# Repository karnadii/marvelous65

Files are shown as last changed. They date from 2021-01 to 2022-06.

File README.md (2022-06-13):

# Marvelous65 Keyboard Series
A 65% wireless hotswap keyboard with Rotary encoder, OLED display and RGB underglow.

## Marvelous65

## Marvelous65 Ergo


## Marvelous65 Split


# WARNING!!!
**FOR ADVANCED USER ONLY!!, THIS IS A DIY KEYBOARD AND NO ONE SELL IT, BUILDING THIS KEYBOARD REQUIRE YOU TO ORDER THE PCB FROM PCB MANU, SOLDER ALL THE COMPONENT YOURSELF, MAKING YOUR OWN PLATE AND CASE YOURSELF. IF YOU ONLY KNOW HOW TO ASSEMBLY A KEYBOARD, THIS IS NOT FOR YOU.**

This keyboard is inspired by luantty2's Candy BLE (https://github.com/luantty2/nRF52840-instruction). When I first saw that I was like "Beautiful! Marvelous!" but that would be nice to make that in 65%. So With no basic knowledge of electronic I brave myself to learn Kicad with the guide of https://wiki.ai03.com/. Basically this is just an nrfmicro 1.4 by Joric embedded in PCB. I also learn some basic Fusion 360 to make a keyboard case and plate.

When I finish designing this, I realize I am not he first one to design this, there is someone in zfrontier forum already done it, it is called Rainbow65, check it out https://www.zfrontier.com/app/flow/e1rpMAd9Nz75.
and there is someone planning an IC for similar layout and feature. 

## Bootloader
Before flashing the firmware, you have to flash the bootloader first. Follow the nrfmicro guide to flash the bootloader https://github.com/joric/nrfmicro/wiki/Bootloader
## Firmware
The firmware will use [ZMK](https://zmkfirmware.dev/). Basic setup ZMK firmware https://zmkfirmware.dev/docs/development/setup.
copy the firmware file to `app/boards/shields`. Edit the keymap or any other feature as you want and build the firmware using the following command 
```bash
west build -p -b nrfmicro_13 -- -DSHIELD=marvelous65_rev2
west build -p -b nrfmicro_13 -- -DSHIELD=marvelous65_ergo
west build -p -b nrfmicro_13 -- -DSHIELD=marvelous65_split_right
west build -p -b nrfmicro_13 -- -DSHIELD=marvelous65_split_left
```

## Features
- Dual mode wireless and wired
- rotary encoder
- oled display 
- rgb underglow
- hotswap (except split version)
- multilayout (except ergo version)

## PCB 
the marvelous65 standard and split version I route it manually. the ergo version I semi auto route it with freerouting. I know a little about electronic, if you have some suggestion or want to coorect the PCB/schematic feel free to make a PR or open an issue.
### Marvelous65
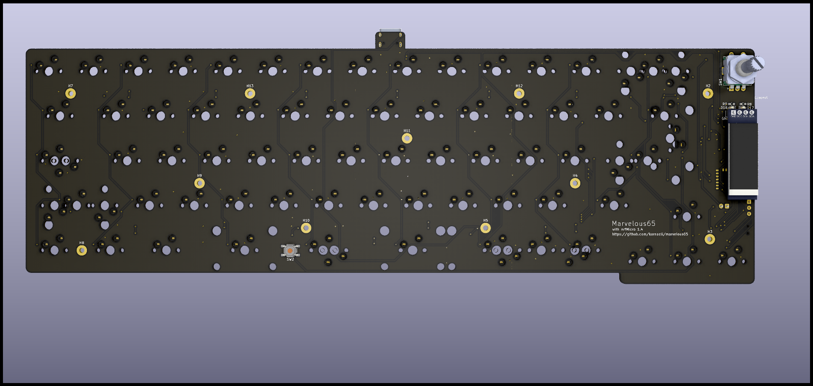
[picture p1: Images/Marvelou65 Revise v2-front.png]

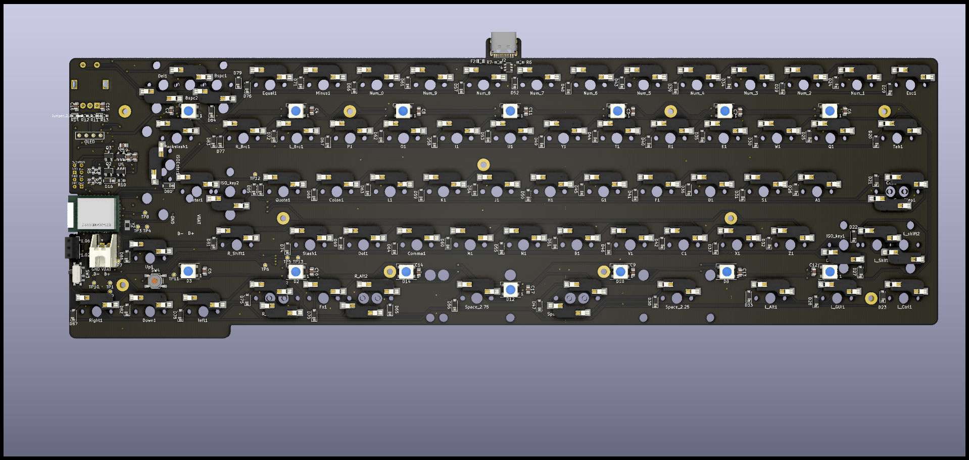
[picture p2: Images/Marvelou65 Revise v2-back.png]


### Marvelous65 Ergo
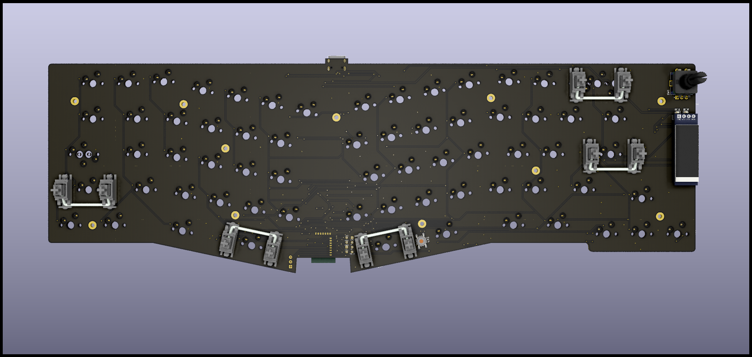
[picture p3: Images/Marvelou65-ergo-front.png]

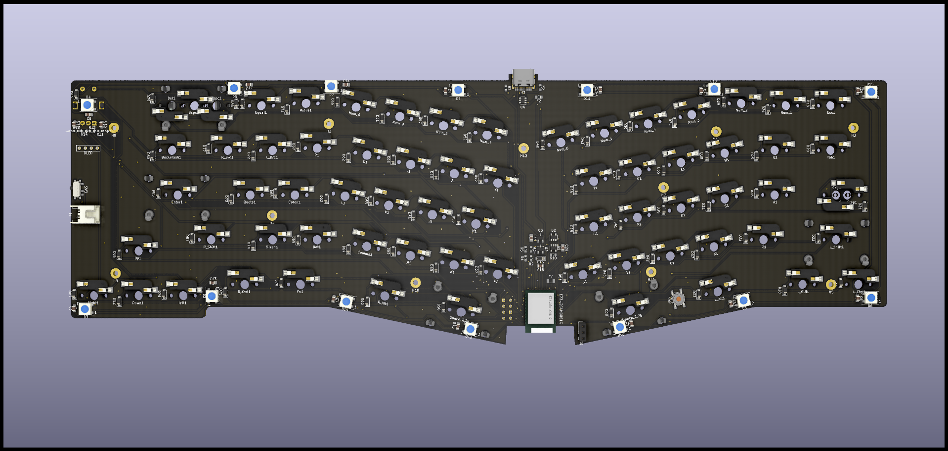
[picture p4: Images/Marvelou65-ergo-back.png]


### Marvelous65 Split
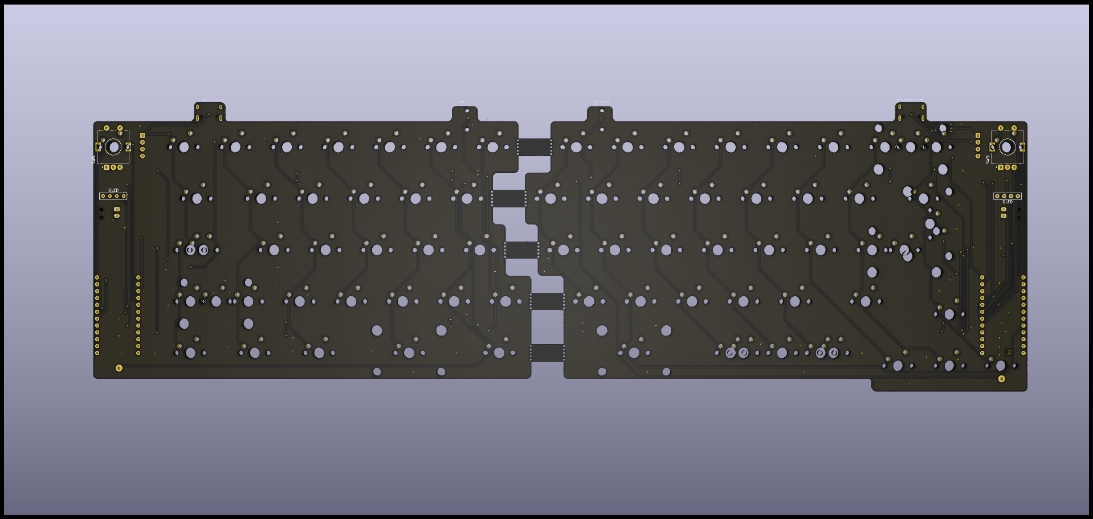
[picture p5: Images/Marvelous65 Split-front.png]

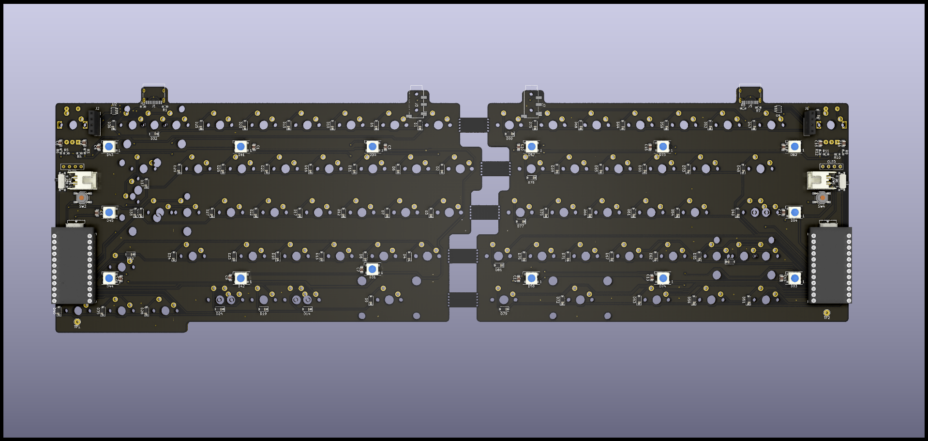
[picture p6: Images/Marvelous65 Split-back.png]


## Layout
### Marvelous65

try it in [KLE](http://www.keyboard-layout-editor.com/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'&_a:6&w:2.25%3B&=Enter&_x:2&a:7%3B&=%3B&@_w:1.25%3B&=&=&_x:0.75&a:6&w:2.25%3B&=Shift&_a:4%3B&=Z&=X&=C&=V&=B&=N&=M&=%3C%0A,&=%3E%0A.&=%3F%0A%2F%2F&_a:6&w:1.75%3B&=Shift%3B&@_y:-0.75&x:17.25&a:7%3B&=%E2%86%91%3B&@_y:-0.25&x:3&a:6&w:1.25%3B&=Ctrl&_w:1.25%3B&=Win&_w:1.25%3B&=Alt&_a:7&w:6.25%3B&=&_a:6%3B&=Alt&=Fn&=Ctrl%3B&@_y:-0.75&x:16.25&a:7%3B&=%E2%86%90&=%E2%86%93&=%E2%86%92%3B&@_x:6.75&w:2.25%3B&=&_w:1.25%3B&=&_w:2.75%3B&=&_w:1.5%3B&=&_w:1.5%3B&=) (Support ISO, stplit backspace, split spacebar, stepped caps)

### Marvelous65 Ergo
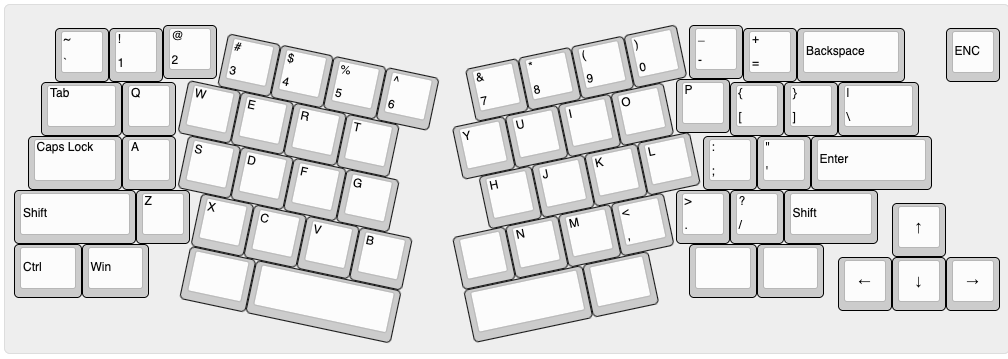
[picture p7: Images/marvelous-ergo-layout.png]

try it in [KLE](http://www.keyboard-layout-editor.com/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'&_a:6&w:2.25%3B&=Enter%3B&@_w:2.25%3B&=Shift&_a:4%3B&=Z&_x:9%3B&=%3E%0A.&=%3F%0A%2F%2F&_a:6&w:1.75%3B&=Shift%3B&@_y:-0.75&x:16.25&a:7%3B&=%E2%86%91%3B&@_y:-0.25&a:6&w:1.25%3B&=Ctrl&_w:1.25%3B&=Win&_x:10&a:7&w:1.25%3B&=&_w:1.25%3B&=%3B&@_y:-0.75&x:15.25%3B&=%E2%86%90&=%E2%86%93&=%E2%86%92%3B&@_r:12&rx:3.05&ry:4.35&y:-1.0999999999999996&x:0.20000000000000018&a:4%3B&=X&=C&=V&=B%3B&@_x:0.20000000000000018&a:7&w:1.25%3B&=&_w:2.75%3B&=%3B&@_rx:3.15&ry:3.35&y:-1.1&x:-0.1499999999999999&a:4%3B&=S&=D&=F&=G%3B&@_rx:3.25&ry:2.35&y:-1.1&x:-0.25%3B&=W&=E&=R&=T%3B&@_rx:3.35&ry:1.35&y:-1.1&x:0.3999999999999999%3B&=%23%0A3&=$%0A4&=%25%0A5&=%5E%0A6%3B&@_r:-12&rx:12.1&y:-1.1&x:-3.5999999999999996%3B&=%2F&%0A7&=*%0A8&=(%0A9&=)%0A0%3B&@_rx:12.2&ry:2.35&y:-1.1&x:-3.9499999999999993%3B&=Y&=U&=I&=O%3B&@_rx:12.3&ry:3.35&y:-1.1&x:-3.5500000000000007%3B&=H&=J&=K&=L%3B&@_rx:12.4&ry:4.35&y:-1.0999999999999996&x:-4.15&a:7%3B&=&_a:4%3B&=N&=M&=%3C%0A,%3B&@_rx:12.525&ry:5.5415&y:-1.2915&x:-4.025&a:7&w:2.25%3B&=&_w:1.25%3B&=) (Support split backspace and stepped caps) 

### Marvelous65 Split
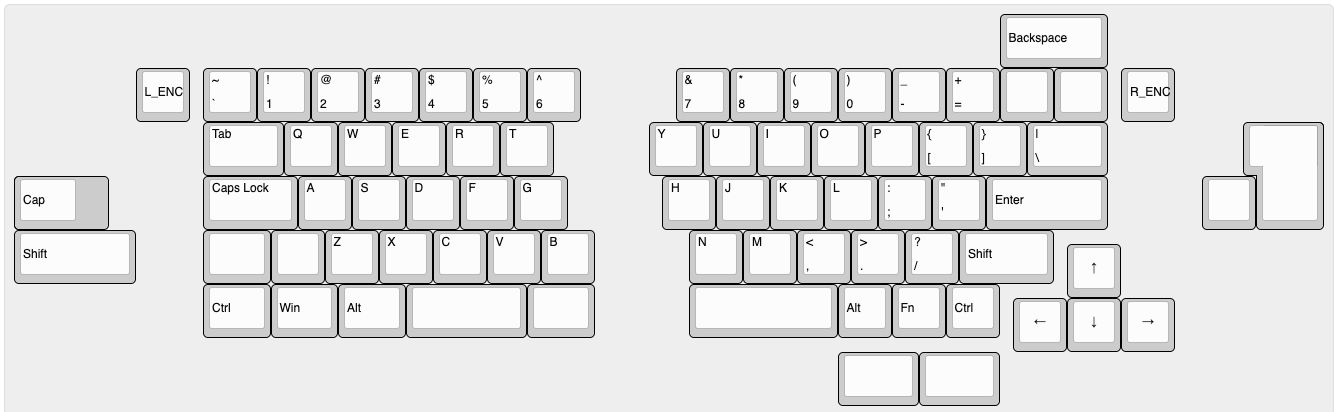
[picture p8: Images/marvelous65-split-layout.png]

try in in [KLE](http://www.keyboard-layout-editor.com/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'&_a:6&w:2.25%3B&=Enter&_x:1.75&a:7%3B&=%3B&@_a:6&w:2.25%3B&=Shift&_x:1.25&a:7&w:1.25%3B&=&=&_a:4%3B&=Z&=X&=C&=V&=B&_x:1.75%3B&=N&=M&=%3C%0A,&=%3E%0A.&=%3F%0A%2F%2F&_a:6&w:1.75%3B&=Shift%3B&@_y:-0.75&x:19.5&a:7%3B&=%E2%86%91%3B&@_y:-0.25&x:3.5&a:6&w:1.25%3B&=Ctrl&_w:1.25%3B&=Win&_w:1.25%3B&=Alt&_a:7&w:2.25%3B&=&_w:1.25%3B&=&_x:1.75&w:2.75%3B&=&_a:6%3B&=Alt&=Fn&=Ctrl%3B&@_y:-0.75&x:18.5&a:7%3B&=%E2%86%90&=%E2%86%93&=%E2%86%92%3B&@_x:15.25&w:1.5%3B&=&_w:1.5%3B&=) (Support ISO, stplit backspace, split spacebar, stepped caps)

## Case
All the case is all 3d printed, except the ergo version have acrylic version case. The case have 3 part, top, middle and bottom. the top and bottom using PLA with 20% infill, while the middle use transparent PLA with 100% infill(to diffuse the underglow RGB) I only know some basic 3d knowledge, so if my case is not to your liking you can design your own case and make a PR or keep it to yourself. Here some rendered Image from fusion 360. The case is top mount. Using M2x5/M2x6 threaded insert and M2 screw (I don't remember the exact size, just buy a set of m2 screw.) The plate for marvelous65 and marvelous65 ergo is sandwiched between top case and bottom case, 

### Marvelous65

### Marvelous65 Ergo
#### Acrylic case

#### 3d printed case


### Marvelous65 Split
I am too lazy while designing this one, so I only design ANSI layout case. The plate is integrated to the case, so if you want different layout you want to make another case.
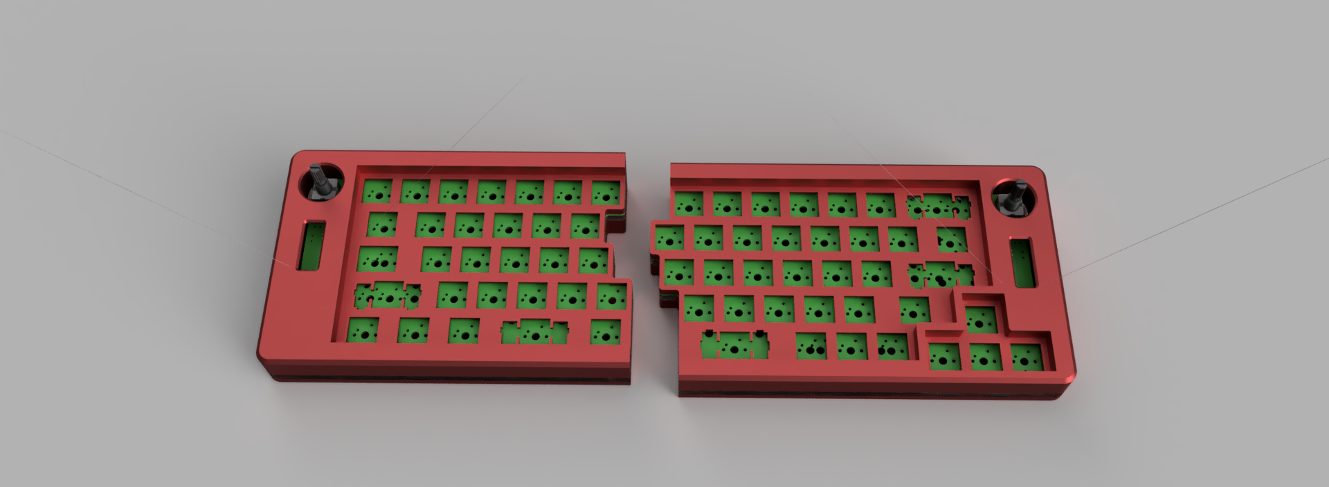
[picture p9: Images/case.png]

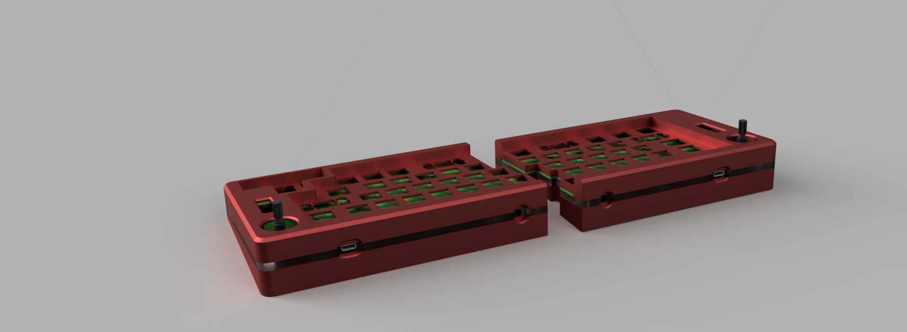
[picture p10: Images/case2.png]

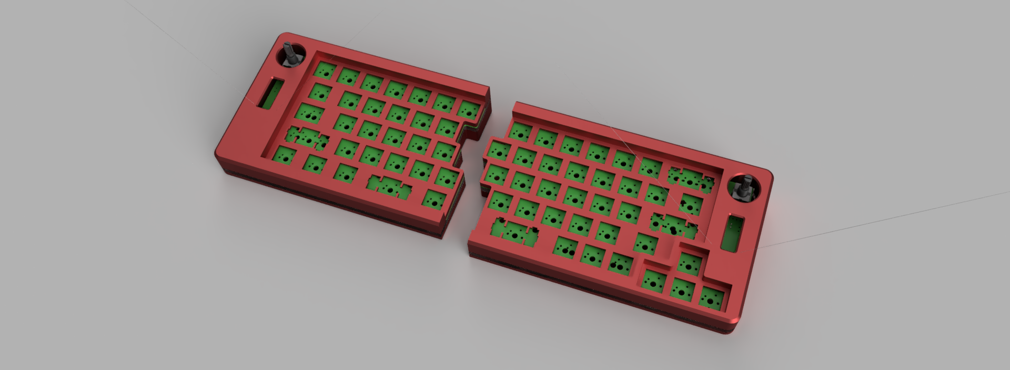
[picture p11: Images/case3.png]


## GIF

https://user-images.githubusercontent.com/18657277/117118259-c4ab1200-adba-11eb-80a2-d7a4a54a5487.mp4

https://user-images.githubusercontent.com/18657277/117118099-8dd4fc00-adba-11eb-8657-396213f3611c.mp4

## BOM
See BOM file for JLCPCB in release page.
also I added IBOM for reference when you will solder it yourself

Marvelous65 IBOM https://karnadii.github.io/marvelous65/Marvelous65/Hardware/bom/ibom.html

Marvelous65-ergo IBOM https://karnadii.github.io/marvelous65/Marvelous65-ergo/Hardware/bom/ibom.html

Marvelous65-split IBOM https://karnadii.github.io/marvelous65/Marvelous65-split/Hardware/bom/ibom.html

## Battery
any lipo battery will do, i use 2.4 JST XH connector. it is better to use 3mm thickness battery.

for the pcb [JST XH2.54 Right Angle Pin Header Connector 2P](https://www.aliexpress.com/item/33008489410.html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,searchweb201602_,searchweb201603_)
for battery [JST XH 2PIN male](https://www.aliexpress.com/item/32996835431.html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,searchweb201602_,searchweb201603_).
All the battery that I purchase have no connector/socket, so I have to solder it myself. Be carefull when soldering, pay attention to the negative and positive of the battery.

I am using this battery. Ignore the label the actual size is 3300mAh.



## TODO
- add acrylic case version
- add multi layout case for split version
- fix ergo version plate (misaligned one screw hole)
- marvelous65 ergo 3d printed case split version
- designing logo and silkscreen
- add assembly guide

## Support Me
Help me order prototype PCB for next revision



## Reference 
- nrfmicro 1.4 https://github.com/joric/nrfmicro/wiki
- nice60 pcb https://github.com/Nicell/nice60
- ZMK firmware https://github.com/zmkfirmware/zmk

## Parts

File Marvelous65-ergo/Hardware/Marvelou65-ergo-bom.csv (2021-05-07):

Comment | Designator | Footprint | LCSC
2 | Bspc2 | MX_Only:MXOnly-2U-Hotswap
10uF | C18,C19,C20 | Capacitor_SMD:C_0805_2012Metric_Pad1.15x1.40mm_HandSolder | C15850
0.1uF | C2,C3,C4,C5,C6,C7,C8,C9,C10,C11,C12,C13,C14,C15,C16,C17 | Capacitor_SMD:C_0805_2012Metric_Pad1.15x1.40mm_HandSolder | C49678
WS2812B | D2,D3,D4,D5,D6,D7,D8,D9,D10,D11,D12,D13,D14,D15 | LED_SMD:LED_WS2812B_PLCC4_5.0x5.0mm_P3.2mm | C114586
1N5819 | D16 | Diode_SMD:D_SOD-123 | C169540
BLUE | D17 | LED_SMD:LED_0603_1608Metric_Pad1.05x0.95mm_HandSolder | C375446
RED | D18 | LED_SMD:LED_0603_1608Metric_Pad1.05x0.95mm_HandSolder | C375450
D | D19,D20,D21,D22,D23,D24,D25,D26,D27,D28,D29,D30,D31,D32,D33,D34,D35,D36,D37,D38,D39,D40,D41,D42,D43,D44,D45,D46,D48,D49,D50,D51,D52,D53,D54,D55,D56,D57,D58,D59,D60,D61,D62,D63,D64,D65,D66,D67,D68,D69,D70,D71,D72,D73,D74,D75,D76,D77,D78,D79,D80,D81,D82,D83,D84,D85,D86,D87 | Diode_SMD:D_SOD-123 | C81598
2.25 | Enter1,L_Shift1 | MX_Only:MXOnly-2.25U-Hotswap
1 | Num_0,Esc1,Num_1,Minus1,Equal1,Bspc1,Del1,Q1,W1,E1,R1,T1,Y1,U1,I1,O1,P1,L_Brc1,R_Brc1,S1,D1,F1,G1,H1,J1,K1,L1,Colon1,Quote1,Z1,X1,C1,V1,B1,N1,M1,Comma1,Dot1,Slash1,Up1,Down1,Right1,left1,A1,Num_2,B2,Num_3,Num_4,Num_5,Num_6,Num_7,Num_8,Num_9 | MX_Only:MXOnly-1U-Hotswap
500mA | F2 | Fuse:Fuse_0805_2012Metric_Pad1.15x1.40mm_HandSolder | C261942
MountingHole | H2,H3,H4,H5,H7,H8,H9,H10,H11,H12,H13 | MountingHole:MountingHole_2.2mm_M2_Pad
USB_C_Receptacle_USB2.0 | J2 | Connector_USB:USB_C_Receptacle_HRO_TYPE-C-31-M-12 | C165948
Conn_01x04 | J3 | nrfmicro:connector_swd
Conn_01x02 | J4 | Connector_JST:JST_XH_S2B-XH-A-1_1x02_P2.50mm_Horizontal | C157931
Conn_01x04 | J5 | nrfmicro:connector_usb
Conn_01x03 | J6 | Connector_PinSocket_2.54mm:PinSocket_1x03_P2.54mm_Vertical
Jumper_2_Bridged | JP1,JP2 | SofleKeyboard-footprint:Jumper
1.25 | L_Ctrl1,L_GUI1,L_Alt1,Cap_Step1 | MX_Only:MXOnly-1.25U-Hotswap
OLED | OL1 | kbd:OLED
AO3407 | Q2,Q3 | Package_TO_SOT_SMD:TSOT-23 | C693136
RPROG_10K/2K | R10 | Resistor_SMD:R_0603_1608Metric_Pad1.05x0.95mm_HandSolder | C22975
10k | R11,R12,R13,R14 | Resistor_SMD:R_0603_1608Metric_Pad1.05x0.95mm_HandSolder | C25804
100K | R2 | Resistor_SMD:R_0603_1608Metric_Pad1.05x0.95mm_HandSolder | C25803
820K | R3 | Resistor_SMD:R_0603_1608Metric_Pad1.05x0.95mm_HandSolder | C23252
2M | R4,R5 | Resistor_SMD:R_0603_1608Metric_Pad1.05x0.95mm_HandSolder | C22976
5.1K | R6,R7 | Resistor_SMD:R_0603_1608Metric_Pad1.05x0.95mm_HandSolder | C23186
1K | R8,R9 | Resistor_SMD:R_0603_1608Metric_Pad1.05x0.95mm_HandSolder | C21190
1 | R_Ctrl1,Fn1,R_Alt1 | MX_Only:MXOnly-1.25U-Hotswap
1.75 | R_Shift1,Cap1 | MX_Only:MXOnly-1.75U-Hotswap
Rotary_Encoder_Switch | SW1 | Rotary_Encoder:RotaryEncoder_Alps_EC11E-Switch_Vertical_H20mm | C470748
SW_PUSH | SW2,SW4 | Button_Switch_SMD:SW_SPST_TL3342 | C318884
SW_SPDT | SW3 | Button_Switch_SMD:SW_SPDT_PCM12 | C221841
2.25 | Space_2.25 | MX_Only:MXOnly-2.25U-Hotswap-ReversedStabilizers
2.75 | Space_2.75 | MX_Only:MXOnly-2.75U-Hotswap-ReversedStabilizers
1.5 | Tab1,Backslash1 | MX_Only:MXOnly-1.5U-Hotswap
AP2112K-3.3 | U2 | Package_TO_SOT_SMD:SOT-23-5 | C51118
E73-2G4M08S1C-52840 | U3 | nrfmicro:E73-2G4M08S1C-52840 | C356849
USBLC6-2SC6 | U4 | Package_TO_SOT_SMD:SOT-23-6 | C558442
TP4054 | U5 | Package_TO_SOT_SMD:SOT-23-5 | C32574
32.768KHZ | Y2 | Crystal:Crystal_SMD_3215-2Pin_3.2x1.5mm | C479190

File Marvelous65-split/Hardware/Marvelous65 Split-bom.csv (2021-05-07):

Comment | Designator | Footprint | LCSC
0.1uF | C1,C2,C3,C4,C5,C6,C7,C8,C9,C10,C11,C12,C13,C14,C15,C16,C17,C18 | Capacitor_SMD:C_0805_2012Metric_Pad1.15x1.40mm_HandSolder | C49678
D | D1,D2,D3,D4,D5,D6,D7,D8,D9,D10,D11,D12,D13,D14,D15,D16,D17,D18,D19,D20,D21,D22,D23,D24,D25,D26,D27,D28,D29,D32,D33,D34,D35,D36,D37,D38,D39,D40,D46,D47,D48,D49,D50,D51,D52,D53,D54,D55,D56,D59,D60,D61,D62,D63,D64,D65,D66,D67,D68,D69,D70,D71,D72,D75,D76,D77,D78,D79,D80,D81 | Diode_SMD:D_SOD-123 | C81598
WS2812B | D30,D31,D41,D42,D43,D44,D45,D57,D58,D73,D74,D82,D83,D84 | LED_SMD:LED_WS2812B_PLCC4_5.0x5.0mm_P3.2mm
MX-NoLED | ISO_ENTER1 | MX_Only:MXOnly-ISO-ROTATED-ReversedStabilizers-NoLED
USB_C_Receptacle_USB2.0 | J1,J5 | Connector_USB:USB_C_Receptacle_HRO_TYPE-C-31-M-12 | C165948
Conn_01x04 | J2,J6 | Connector_PinSocket_2.54mm:PinSocket_1x04_P2.54mm_Vertical
AudioJack4 | J3,J7 | Connector_Audio:Jack_3.5mm_PJ320D_Horizontal | C15139
Conn_01x02 | J4,J8 | Connector_JST:JST_XH_S2B-XH-A_1x02_P2.50mm_Horizontal | C157931
Jumper_2_Bridged | JP1,JP2,JP3,JP4 | SofleKeyboard-footprint:Jumper
1.5 | K_BACKSLASH1,K_CTRL1,K_ALT1,K_TAB1 | MX_Only:MXOnly-1.5U-NoLED
2 | K_BSPC1 | MX_Only:MXOnly-2U-NoLED
2.25 | K_ENTER1,K_LSHIFT1 | MX_Only:MXOnly-2.25U-NoLED
MX-NoLED | K_FN2 | MX_Only:MXOnly-1.25U-NoLED
MX-NoLED | K_NUM0,K_MINUS1,K_EQUAL1,K_O1,K_P1,K_L_PAR1,K_R_PAR1,K_ENC1,K_DEL1,K_I1,K_U1,K_Y1,K_H1,K_J1,K_K1,K_L1,K_DOT1,K_SLASH1,K_UP1,K_QUOTE1,K_COLON1,K_COMMA1,K_M1,K_N1,K_FN1,K_RIGHT1,K_DOWN1,K_LEFT1,ISO_KEY1,L_ENC1,K_GRAVE1,K_NUM1,K_Q1,K_W1,K_E1,K_R1,K_T1,K_A1,K_S1,K_D1,K_F1,K_G1,K_ISO_K1,K_Z1,K_X1,K_C1,K_V1,K_B1,K_ALT2,K_CTRL2,K_BSPC2,K_NUM2,K_NUM3,K_NUM4,K_NUM5,K_NUM6,K_NUM7,K_NUM8,K_NUM9 | MX_Only:MXOnly-1U-NoLED
1.75 | K_RSHIFT1,K_CAPS1 | MX_Only:MXOnly-1.75U-NoLED
1.25 | K_SHIFT_ISO1,K_WIN1,K_CAPS_STEP1,K_CTRL3,K_ALT3 | MX_Only:MXOnly-1.25U-NoLED
2.75 | K_SPACE1 | MX_Only:MXOnly-2.75U-ReversedStabilizers-NoLED
2.25 | K_SPACE2 | MX_Only:MXOnly-2.25U-ReversedStabilizers-NoLED
OLED | OL1,OL2 | kbd:OLED
5.1K | R1,R2,R7,R8 | Resistor_SMD:R_0603_1608Metric_Pad1.05x0.95mm_HandSolder | C23186
10k | R3,R4,R5,R6,R9,R10,R11,R12 | Resistor_SMD:R_0603_1608Metric_Pad1.05x0.95mm_HandSolder | C25804
SW_DPDT_x2 | SW1,SW6 | Button_Switch_SMD:SW_SPDT_PCM12 | C221841
SW_PUSH | SW2,SW4 | Button_Switch_SMD:SW_SPST_TL3342 | C318884
Rotary_Encoder_Switch | SW3,SW5 | Rotary_Encoder:RotaryEncoder_Alps_EC11E-Switch_Vertical_H20mm | C470748
TestPoint | TP1,TP2 | TestPoint:TestPoint_THTPad_D2.5mm_Drill1.2mm
ProMicro | U1,U3 | kbd:ProMicro_v3
USBLC6-2SC6 | U2,U4 | Package_TO_SOT_SMD:SOT-23-6 | C558442

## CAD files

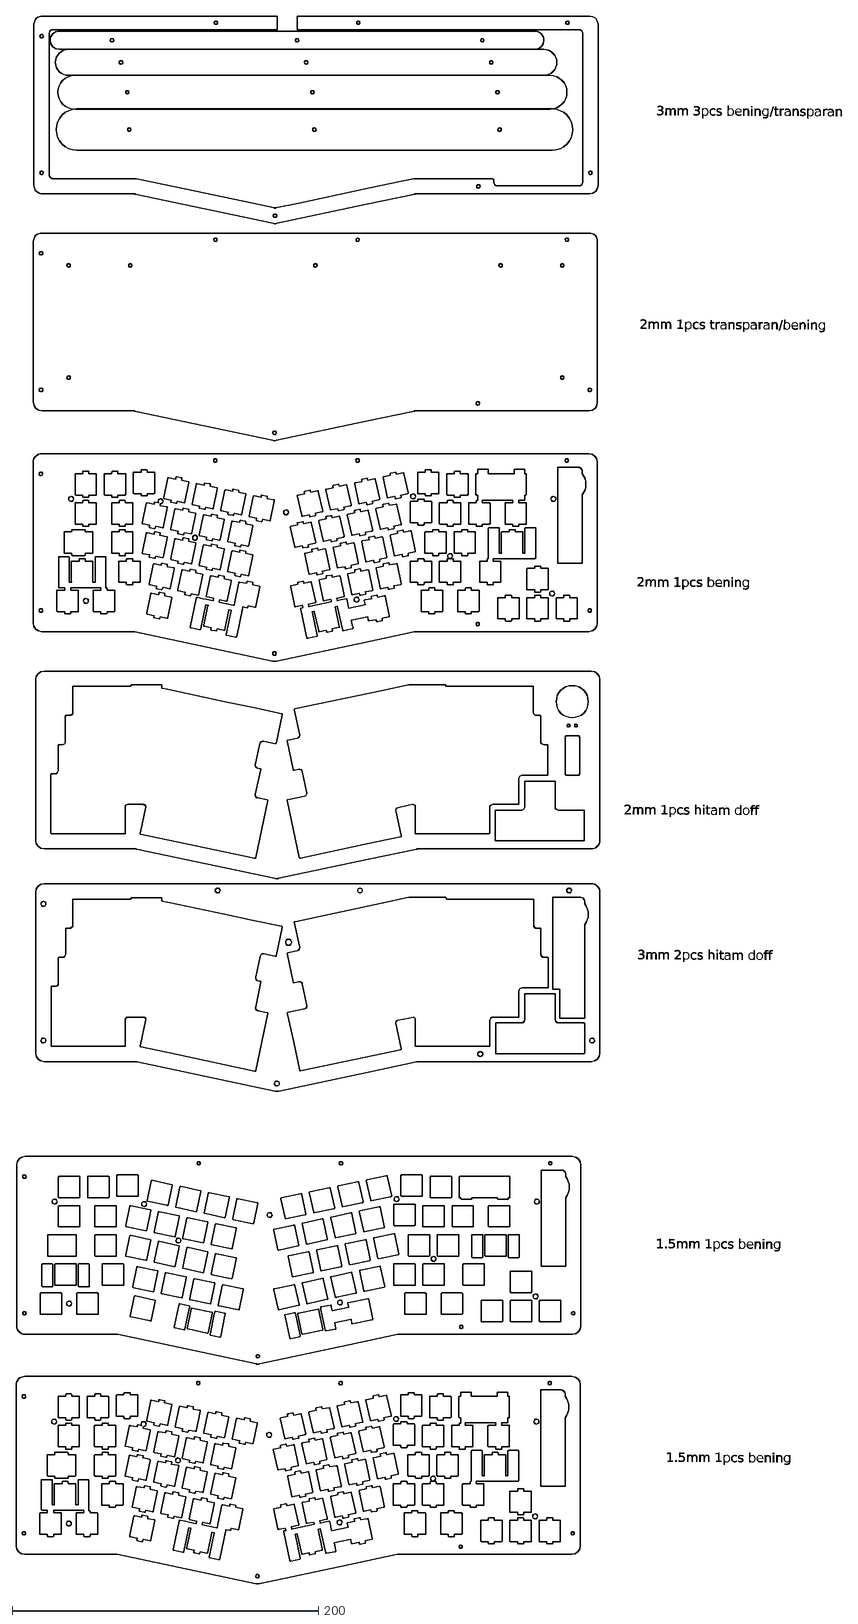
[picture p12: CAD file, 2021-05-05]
Marvelous65-ergo/Case/Acrylic/marvelous ergo akrilik case v2.dxf
3mm 2pcs hitam doff
2mm 1pcs hitam doff
2mm 1pcs bening
2mm 1pcs transparan/bening
3mm 3pcs bening/transparan
1.5mm 1pcs bening

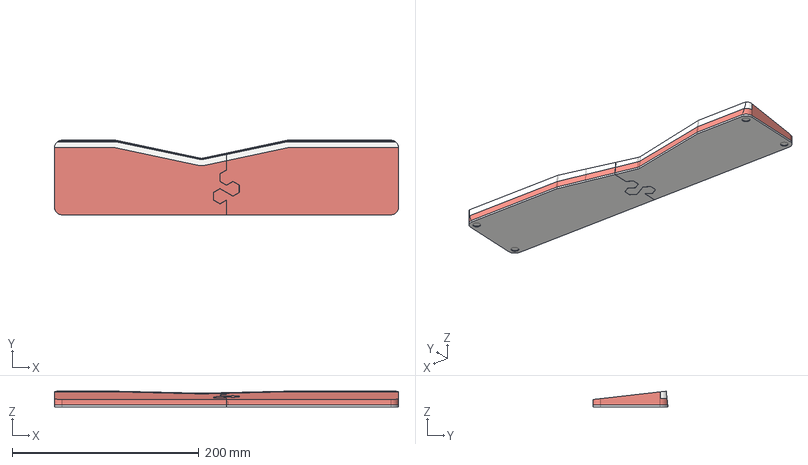
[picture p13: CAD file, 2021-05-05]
Marvelous65-ergo/Misc/marvelous65 ergo palm rest v9.step
368.7 x 80.0 x 16.8 mm

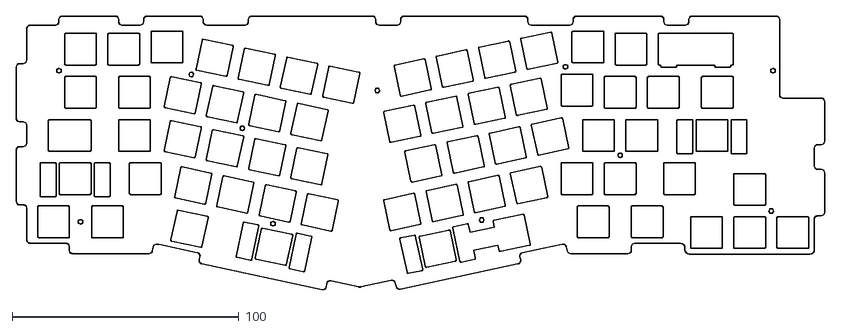
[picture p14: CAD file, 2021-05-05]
Marvelous65-ergo/Plate/marvelous-ergo-plate.dxf
356.7 x 120.8

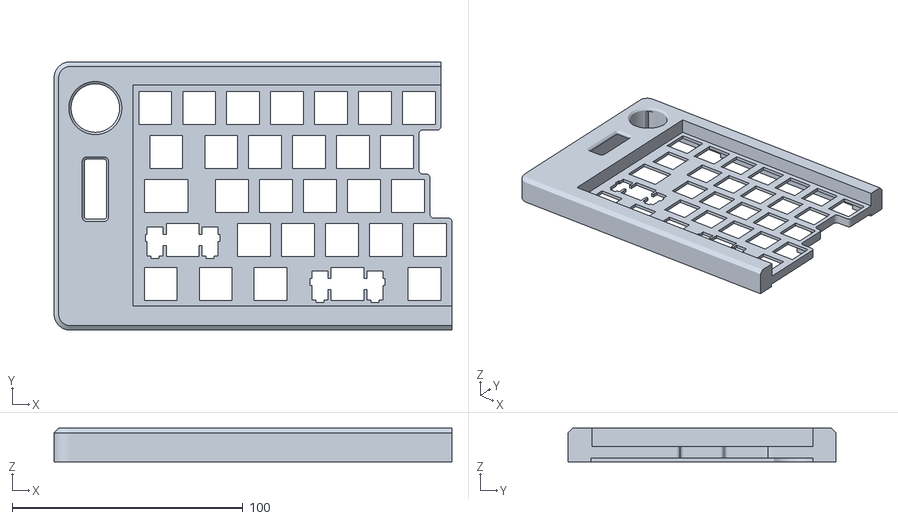
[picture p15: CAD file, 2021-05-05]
Marvelous65-split/Case/Left top case.stl
172.4 x 116.3 x 14.6

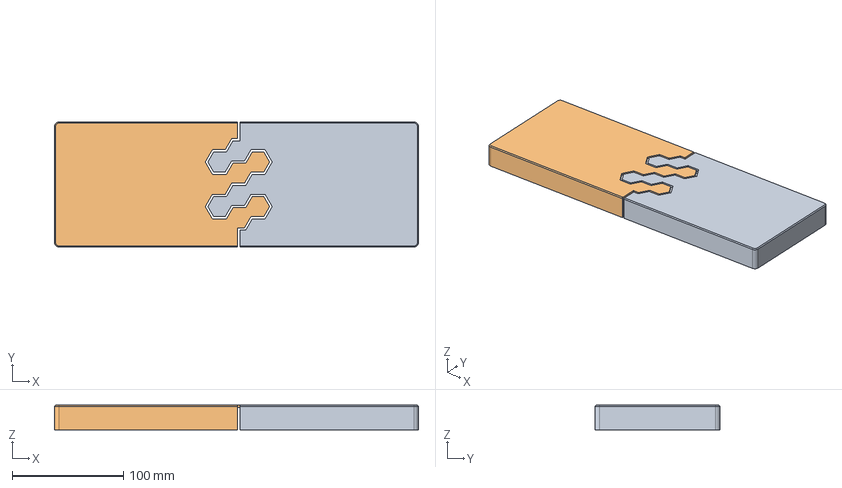
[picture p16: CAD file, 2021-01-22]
Marvelous65/Misc/Marvelous65 Dust cover.step
326.6 x 112.3 x 22.0 mm

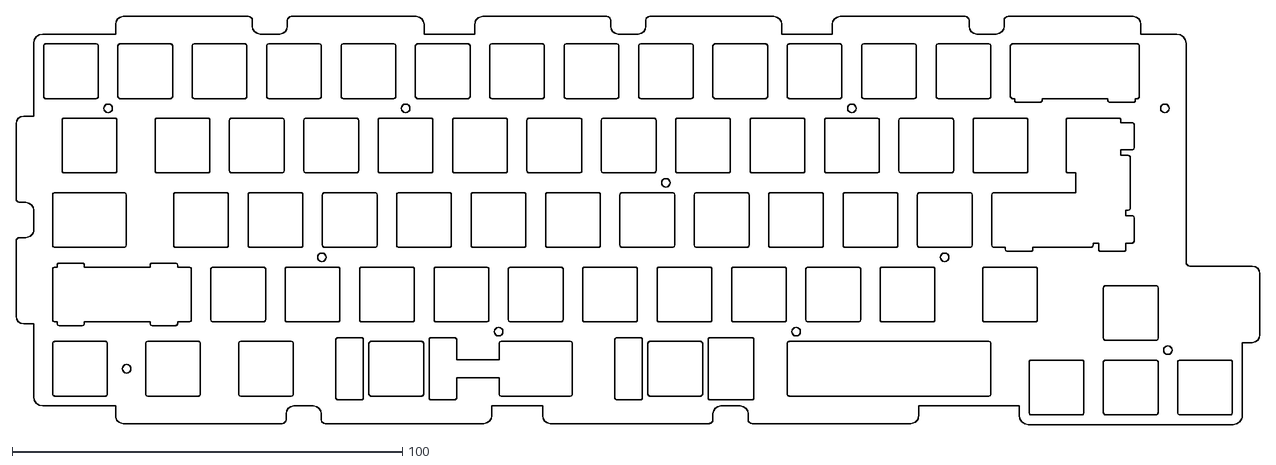
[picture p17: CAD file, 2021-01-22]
Marvelous65/Plate/marvelous65 plate.dxf
318.6 x 104.5

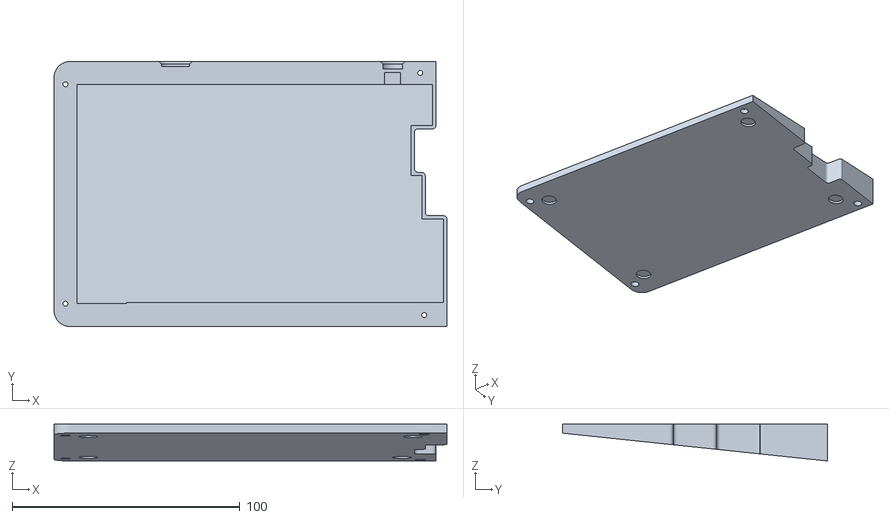
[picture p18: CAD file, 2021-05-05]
Marvelous65-split/Case/left bottom case.stl
172.4 x 116.3 x 16.2

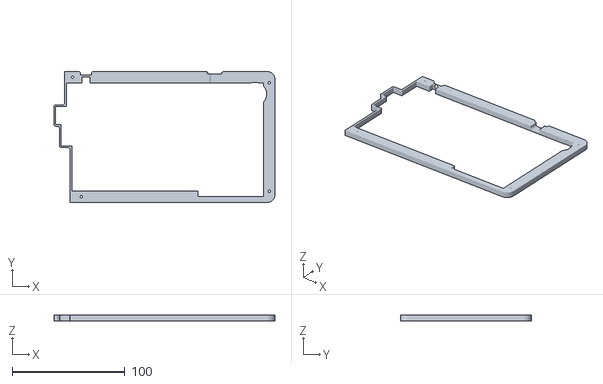
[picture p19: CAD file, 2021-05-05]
Marvelous65-split/Case/Right middle case.stl
196.2 x 116.2 x 5.00

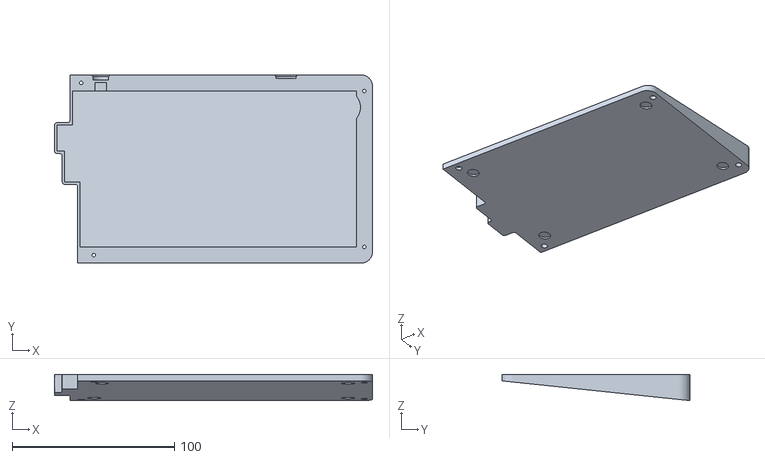
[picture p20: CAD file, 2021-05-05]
Marvelous65-split/Case/Right bottom case.stl
196.2 x 116.2 x 16.2

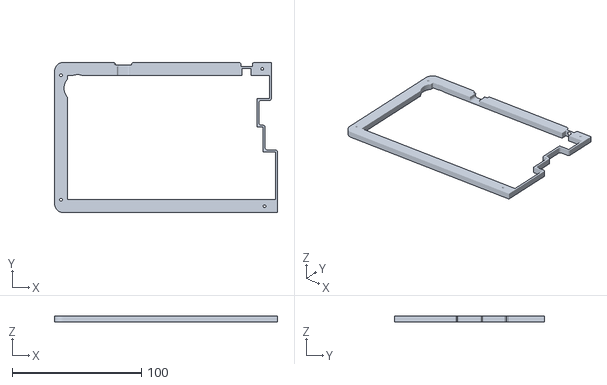
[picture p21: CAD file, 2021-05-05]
Marvelous65-split/Case/Left middle case.stl
172.4 x 116.3 x 5.00

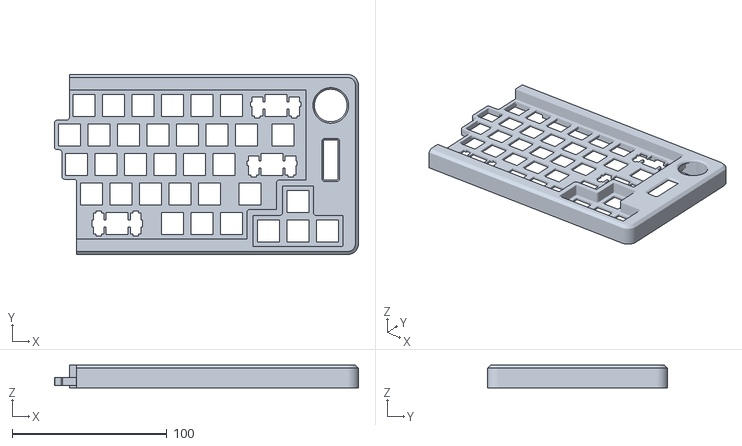
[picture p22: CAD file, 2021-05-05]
Marvelous65-split/Case/Right Top case.stl
196.2 x 116.2 x 14.7

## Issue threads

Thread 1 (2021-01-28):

Hello

xiaojia998, 2021-01-28:
I don’t know if I can buy one of your pcbs. Can I add a discord or WeChat easily?

karnadii, 2021-01-28:
Thanks for your interest in my marvelous65. there are some minor mistake in
my version 2 pcb. So i need more revision. I don't sell my marvelous65 yet.
But don't worry, I plan to make it open source. So you have to wait a
little bit, cause I don't have the time to do revision yet. I will put
donate link in the future in github. So if you feel gratitude you can
donate to me latter.

Thank you.

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

xiaojia998, 2021-01-28:
Thank you for your reply, looking forward to future v2, I would love to donate if I can!

karnadii, 2021-01-28:
My discord is karnadi#6627 if you want in touch. I dont have a wechat
currently.

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

karnadii, 2021-05-05:
Just pushed the pcb files to the repo, if you are still interested you can order the pcb at JLC or pcbway your own

xiaojia998, 2021-05-05:
> 只需将pcb文件推送到仓库中，如果您仍然有兴趣，可以在JLC或pcbway上订购pcb

Thanks for sharing, I've got the pcb file and placed an order with JLC, how do I get the relevant firmware?

karnadii, 2021-05-05:
don't worry with the firmware, everything ready. I will link it to readme when I finish organizing the files.

xiaojia998, 2021-05-05:
Great, thanks!

Closed 2021-05-05.

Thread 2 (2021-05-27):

[POLL] Which one do you like the most?

karnadii, 2021-05-27:
Please vote, which one you like the most so I can focus on developing the case pcb and the feature more.

1. Original version
2. Ergo version
3. Split version

also if you building one and have a question, let me know in the comment bellow or via discord karnadi#6627

drewfowler, 2021-05-27:
Ergo!

karnadii, 2021-05-28:
> Ergo!

Right, in the beginning I focus on the regular version, now I can't go back to the regular version since I use the ergo/alice like version. I am planning to add more feature like trackpoint and other feature on the ergo version, since the pcb has more space than the regular version. I just wait for the ZMK support ready first untill I add another feature.

drewfowler, 2021-05-28:
I think it is awesome how it is. It is the top board on my list to build.

aotd1, 2021-06-02:
Split! =)
I'm trying to find a split true wireless keyboard for a few months, and the lasts I found!
The last thing that stops me - there is no hot-swap for the split version. And I can't find nice!nano boards to buy (is it true that this project uses it?)

karnadii, 2021-06-02:
My split use nrfmicro https://github.com/joric/nrfmicro
Kind of nice!nano replacement (DIY). Or you can use bluemicro too https://store.jpconstantineau.com/#/item/BMicro840

vuhuynh95, 2021-06-06:
Ergo!!!

I like Alice layout.

Opiowo, 2021-06-07:
Split

karnadii, 2021-06-07:
> Ergo!!!
>
> I like Alice layout.

actually I am working on wireless alice right now, build according alice plate, should be compatible with alice clone case (not proven yet). 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

huythong1991, 2021-06-08:
Normal and Ergo !!!!!

vuhuynh95, 2021-06-08:
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

I am really looking forward to seeing the wireless version.

Closed 2022-06-13.

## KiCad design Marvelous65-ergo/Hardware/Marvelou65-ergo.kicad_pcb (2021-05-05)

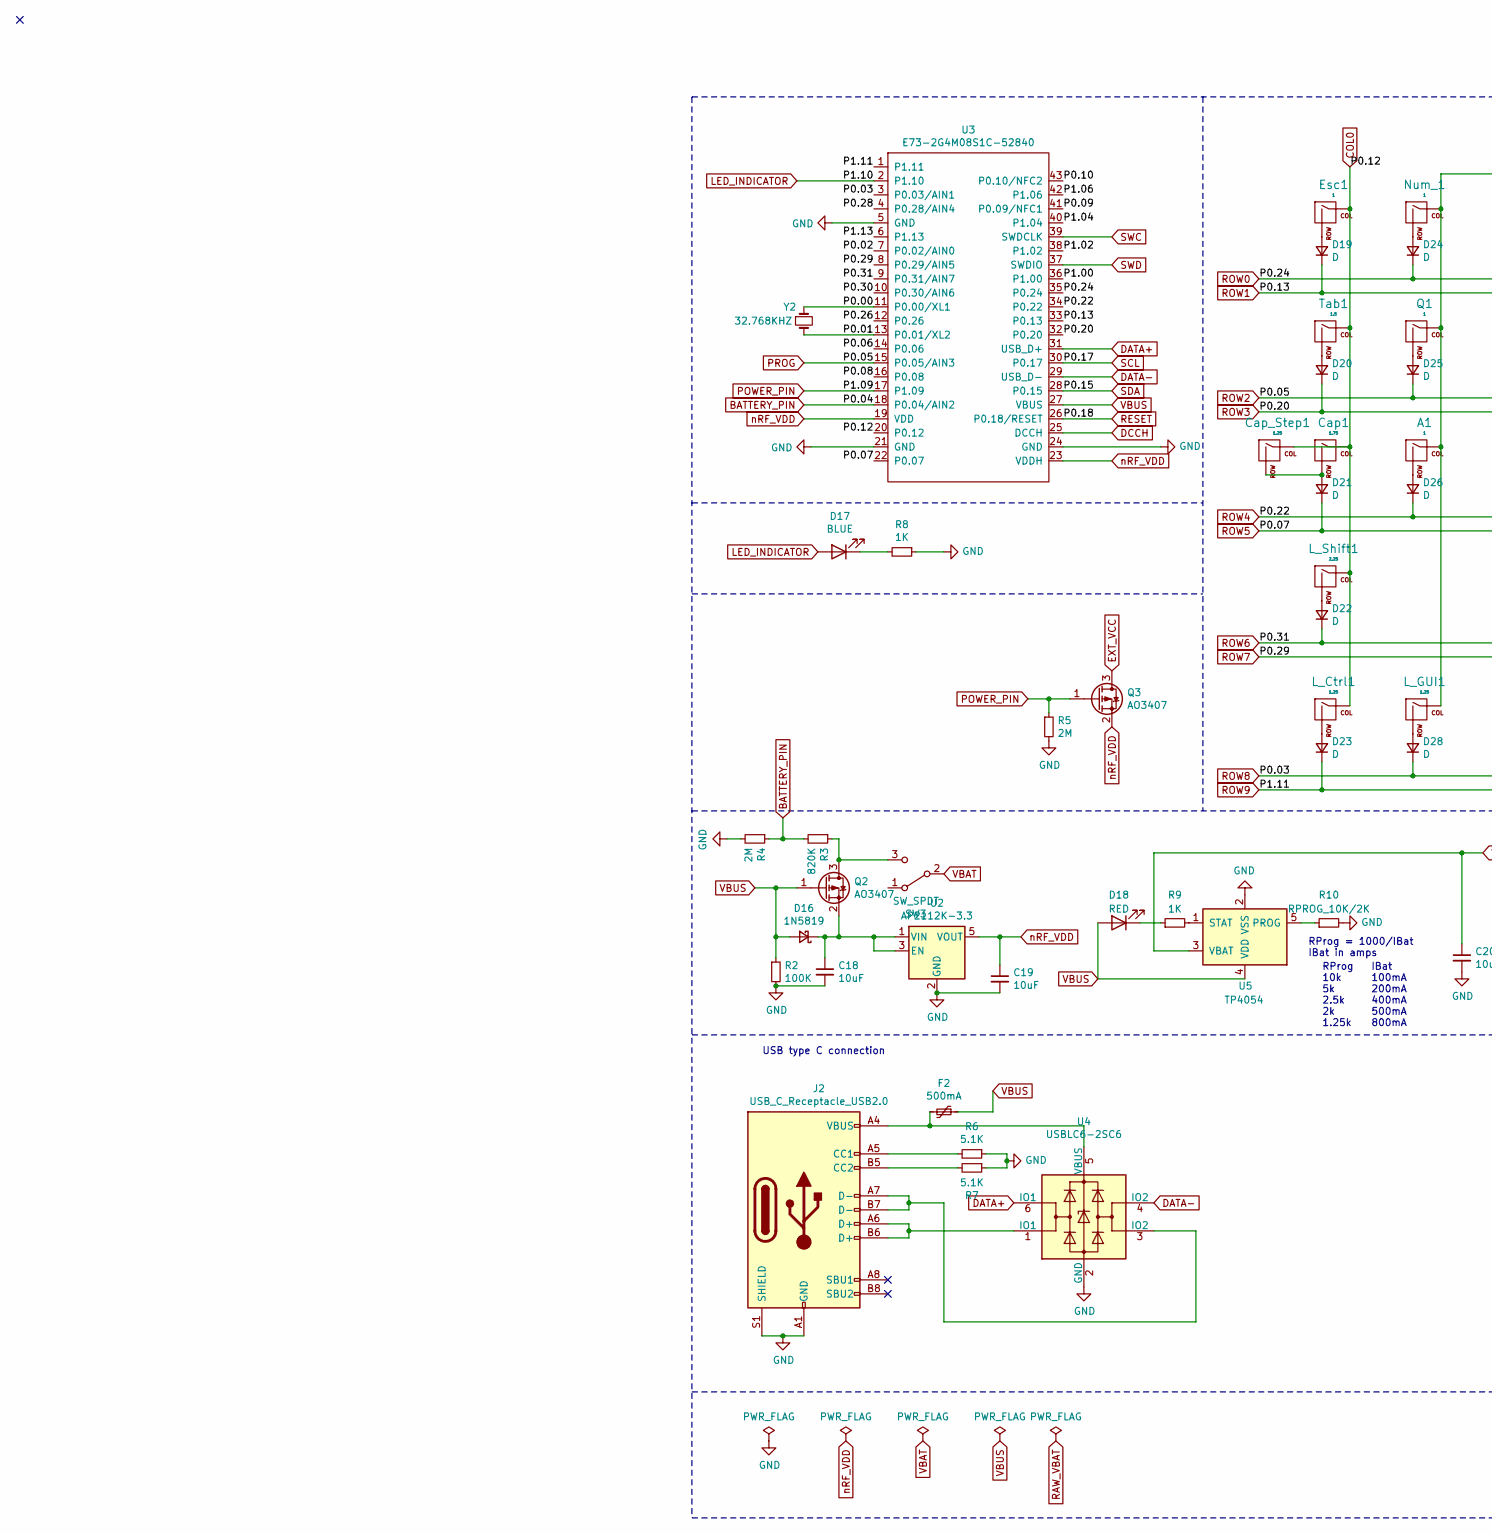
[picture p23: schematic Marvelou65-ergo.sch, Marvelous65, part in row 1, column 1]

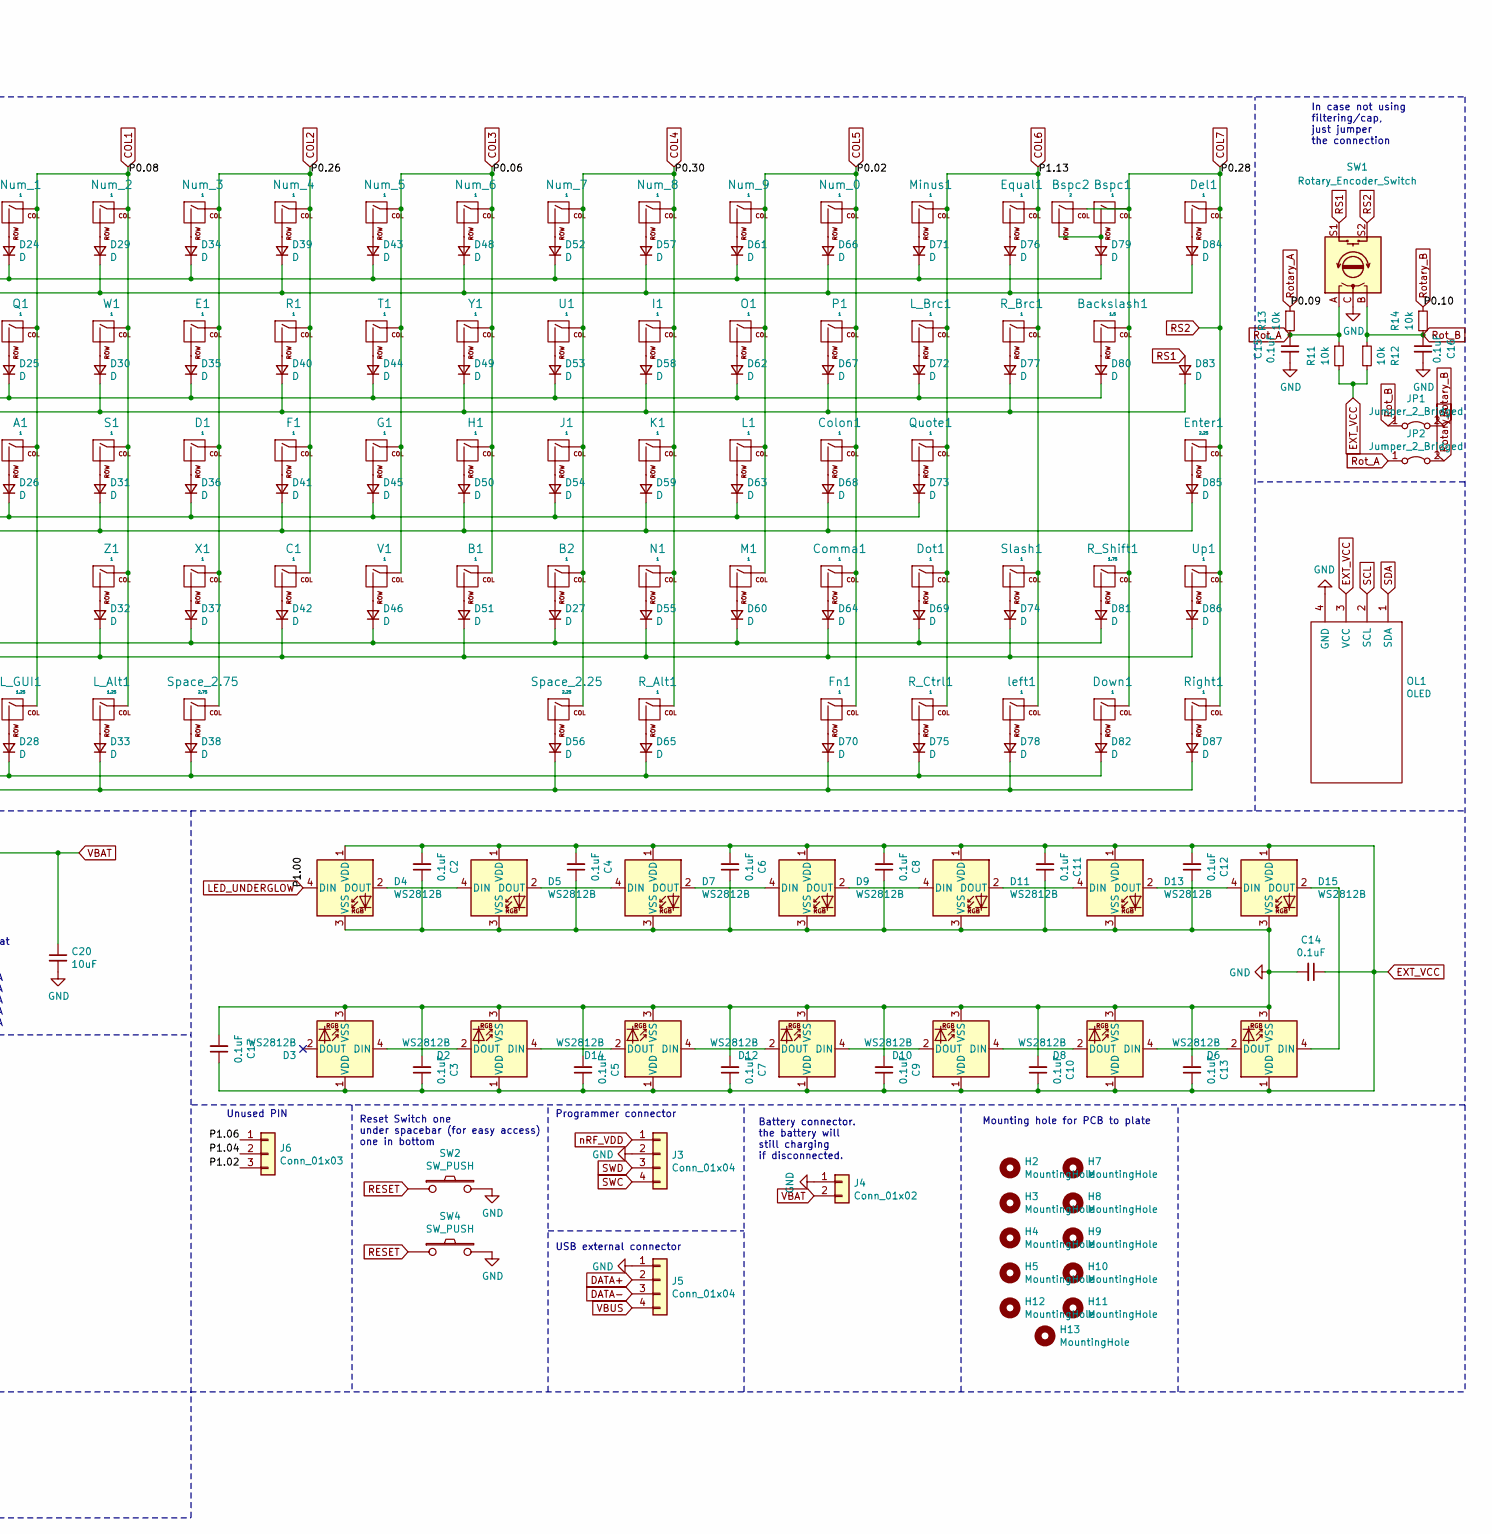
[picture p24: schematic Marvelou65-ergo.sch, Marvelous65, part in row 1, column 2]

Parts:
A1: 1; MXOnly-1U-Hotswap
B1, B2: 1; MXOnly-1U-Hotswap
Backslash1: 1.5; MXOnly-1.5U-Hotswap
Bspc1: 1; MXOnly-1U-Hotswap
Bspc2: 2; MXOnly-2U-Hotswap
C1: 1; MXOnly-1U-Hotswap
C2, C3, C4, C5, C6, C7, C8, C9, C10, C11, C12, C13, C14, C15, C16, C17: 0.1uF; C_0805_2012Metric_Pad1.15x1.40mm_HandSolder; LCSC C49678
C18, C19, C20: 10uF; C_0805_2012Metric_Pad1.15x1.40mm_HandSolder; LCSC C15850
Cap1: 1.75; MXOnly-1.75U-Hotswap
Cap_Step1: 1.25; MXOnly-1.25U-Hotswap
Colon1: 1; MXOnly-1U-Hotswap
Comma1: 1; MXOnly-1U-Hotswap
D1: 1; MXOnly-1U-Hotswap
D2, D3, D4, D5, D6, D7, D8, D9, D10, D11, D12, D13, D14, D15: WS2812B; LED_WS2812B_PLCC4_5.0x5.0mm_P3.2mm; LCSC C114586
D16: 1N5819; D_SOD-123; LCSC C169540
D17: BLUE; LED_0603_1608Metric_Pad1.05x0.95mm_HandSolder; LCSC C375446
D18: RED; LED_0603_1608Metric_Pad1.05x0.95mm_HandSolder; LCSC C375450
D19, D20, D21, D22, D23, D24, D25, D26, D27, D28, D29, D30, D31, D32, D33, D34, D35, D36, D37, D38, D39, D40, D41, D42, D43, D44, D45, D46, D48, D49, D50, D51, D52, D53, D54, D55, D56, D57, D58, D59, D60, D61, D62, D63, D64, D65, D66, D67, D68, D69, D70, D71, D72, D73, D74, D75, D76, D77, D78, D79, D80, D81, D82, D83, D84, D85, D86, D87: D; D_SOD-123; LCSC C81598
Del1: 1; MXOnly-1U-Hotswap
Dot1: 1; MXOnly-1U-Hotswap
Down1: 1; MXOnly-1U-Hotswap
E1: 1; MXOnly-1U-Hotswap
Enter1: 2.25; MXOnly-2.25U-Hotswap
Equal1: 1; MXOnly-1U-Hotswap
Esc1: 1; MXOnly-1U-Hotswap
F1: 1; MXOnly-1U-Hotswap
F2: 500mA; Fuse_0805_2012Metric_Pad1.15x1.40mm_HandSolder; LCSC C261942
Fn1: 1; MXOnly-1.25U-Hotswap
G1: 1; MXOnly-1U-Hotswap
H1: 1; MXOnly-1U-Hotswap
H2, H3, H4, H5, H7, H8, H9, H10, H11, H12, H13: MountingHole; MountingHole_2.2mm_M2_Pad
I1: 1; MXOnly-1U-Hotswap
J1: 1; MXOnly-1U-Hotswap
J2: USB_C_Receptacle_USB2.0; USB_C_Receptacle_HRO_TYPE-C-31-M-12; LCSC C165948
J3: Conn_01x04; connector_swd
J4: Conn_01x02; JST_XH_S2B-XH-A-1_1x02_P2.50mm_Horizontal; LCSC C157931
J5: Conn_01x04; connector_usb
J6: Conn_01x03; PinSocket_1x03_P2.54mm_Vertical
JP1, JP2: Jumper_2_Bridged; Jumper
K1: 1; MXOnly-1U-Hotswap
L1: 1; MXOnly-1U-Hotswap
L_Alt1: 1.25; MXOnly-1.25U-Hotswap
L_Brc1: 1; MXOnly-1U-Hotswap
L_Ctrl1: 1.25; MXOnly-1.25U-Hotswap
L_GUI1: 1.25; MXOnly-1.25U-Hotswap
L_Shift1: 2.25; MXOnly-2.25U-Hotswap
M1: 1; MXOnly-1U-Hotswap
Minus1: 1; MXOnly-1U-Hotswap
N1: 1; MXOnly-1U-Hotswap
Num_0, Num_1, Num_2, Num_3, Num_4, Num_5, Num_6, Num_7, Num_8, Num_9: 1; MXOnly-1U-Hotswap
O1: 1; MXOnly-1U-Hotswap
OL1: OLED
P1: 1; MXOnly-1U-Hotswap
Q1: 1; MXOnly-1U-Hotswap
Q2, Q3: AO3407; TSOT-23; LCSC C693136
Quote1: 1; MXOnly-1U-Hotswap
R1: 1; MXOnly-1U-Hotswap
R2: 100K; R_0603_1608Metric_Pad1.05x0.95mm_HandSolder; LCSC C25803
R3: 820K; R_0603_1608Metric_Pad1.05x0.95mm_HandSolder; LCSC C23252
R4, R5: 2M; R_0603_1608Metric_Pad1.05x0.95mm_HandSolder; LCSC C22976
R6, R7: 5.1K; R_0603_1608Metric_Pad1.05x0.95mm_HandSolder; LCSC C23186
R8, R9: 1K; R_0603_1608Metric_Pad1.05x0.95mm_HandSolder; LCSC C21190
R10: RPROG_10K/2K; R_0603_1608Metric_Pad1.05x0.95mm_HandSolder; LCSC C22975
R11, R12, R13, R14: 10k; R_0603_1608Metric_Pad1.05x0.95mm_HandSolder; LCSC C25804
R_Alt1: 1; MXOnly-1.25U-Hotswap
R_Brc1: 1; MXOnly-1U-Hotswap
R_Ctrl1: 1; MXOnly-1.25U-Hotswap
R_Shift1: 1.75; MXOnly-1.75U-Hotswap
Right1: 1; MXOnly-1U-Hotswap
S1: 1; MXOnly-1U-Hotswap
SW1: Rotary_Encoder_Switch; RotaryEncoder_Alps_EC11E-Switch_Vertical_H20mm; LCSC C470748
SW2, SW4: SW_PUSH; SW_SPST_TL3342; LCSC C318884
SW3: SW_SPDT; SW_SPDT_PCM12; LCSC C221841
Slash1: 1; MXOnly-1U-Hotswap
Space_2.25: 2.25; MXOnly-2.25U-Hotswap-ReversedStabilizers
Space_2.75: 2.75; MXOnly-2.75U-Hotswap-ReversedStabilizers
T1: 1; MXOnly-1U-Hotswap
Tab1: 1.5; MXOnly-1.5U-Hotswap
U1: 1; MXOnly-1U-Hotswap
U2: AP2112K-3.3; SOT-23-5; LCSC C51118
U3: E73-2G4M08S1C-52840; LCSC C356849
U4: USBLC6-2SC6; SOT-23-6; LCSC C558442
U5: TP4054; SOT-23-5; LCSC C32574
Up1: 1; MXOnly-1U-Hotswap
V1: 1; MXOnly-1U-Hotswap
W1: 1; MXOnly-1U-Hotswap
X1: 1; MXOnly-1U-Hotswap
Y1: 1; MXOnly-1U-Hotswap
Y2: 32.768KHZ; Crystal_SMD_3215-2Pin_3.2x1.5mm; LCSC C479190
Z1: 1; MXOnly-1U-Hotswap
left1: 1; MXOnly-1U-Hotswap

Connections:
/P0.00: U3.11 (P0.00/XL1), Y2.1
/P0.01: U3.13 (P0.01/XL2), Y2.2
/P1.02: J6.3, U3.38 (P1.02)
/P1.04: J6.2, U3.40 (P1.04)
/P1.06: J6.1, U3.42 (P1.06)
BATTERY_PIN: R3.2, R4.1, U3.18 (P0.04/AIN2)
COL0: Cap1.1 (COL), Cap_Step1.1 (COL), Esc1.1 (COL), L_Ctrl1.1 (COL), L_Shift1.1 (COL), Tab1.1 (COL), U3.20 (P0.12)
COL1: A1.1 (COL), L_Alt1.1 (COL), L_GUI1.1 (COL), Num_1.1 (COL), Num_2.1 (COL), Q1.1 (COL), S1.1 (COL), U3.16 (P0.08), W1.1 (COL), Z1.1 (COL)
COL2: C1.1 (COL), D1.1 (COL), E1.1 (COL), F1.1 (COL), Num_3.1 (COL), Num_4.1 (COL), R1.1 (COL), Space_2.75.1 (COL), U3.12 (P0.26), X1.1 (COL)
COL3: B1.1 (COL), G1.1 (COL), H1.1 (COL), Num_5.1 (COL), Num_6.1 (COL), T1.1 (COL), U3.14 (P0.06), V1.1 (COL), Y1.1 (COL)
COL4: B2.1 (COL), I1.1 (COL), J1.1 (COL), K1.1 (COL), N1.1 (COL), Num_7.1 (COL), Num_8.1 (COL), R_Alt1.1 (COL), Space_2.25.1 (COL), U1.1 (COL), U3.10 (P0.30/AIN6)
COL5: Colon1.1 (COL), Comma1.1 (COL), Fn1.1 (COL), L1.1 (COL), M1.1 (COL), Num_0.1 (COL), Num_9.1 (COL), O1.1 (COL), P1.1 (COL), U3.7 (P0.02/AIN0)
COL6: Dot1.1 (COL), Equal1.1 (COL), L_Brc1.1 (COL), Minus1.1 (COL), Quote1.1 (COL), R_Brc1.1 (COL), R_Ctrl1.1 (COL), Slash1.1 (COL), U3.6 (P1.13), left1.1 (COL)
COL7: Backslash1.1 (COL), Bspc1.1 (COL), Bspc2.1 (COL), Del1.1 (COL), Down1.1 (COL), Enter1.1 (COL), R_Shift1.1 (COL), Right1.1 (COL), SW1.S2, U3.4 (P0.28/AIN4), Up1.1 (COL)
DATA+: J5.2, U3.31 (USB_D+), U4.6 (IO1)
DATA-: J5.3, U3.29 (USB_D-), U4.4 (IO2)
DCCH: U3.25 (DCCH)
EXT_VCC: C2.2, C3.1, C4.2, C5.1, C6.2, C7.1, C8.2, C9.1, C10.1, C11.2, C12.2, C13.1, C14.1, C17.1, D2.1 (VDD), D3.1 (VDD), D4.1 (VDD), D5.1 (VDD), D6.1 (VDD), D7.1 (VDD), D8.1 (VDD), D9.1 (VDD), D10.1 (VDD), D11.1 (VDD), D12.1 (VDD), D13.1 (VDD), D14.1 (VDD), D15.1 (VDD), OL1.3 (VCC), Q3.3 (D), R11.2, R12.2
GND: C2.1, C3.2, C4.1, C5.2, C6.1, C7.2, C8.1, C9.2, C10.2, C11.1, C12.1, C13.2, C14.2, C15.2, C16.2, C17.2, C18.2, C19.2, C20.2, D2.3 (VSS), D3.3 (VSS), D4.3 (VSS), D5.3 (VSS), D6.3 (VSS), D7.3 (VSS), D8.3 (VSS), D9.3 (VSS), D10.3 (VSS), D11.3 (VSS), D12.3 (VSS), D13.3 (VSS), D14.3 (VSS), D15.3 (VSS), J2.A1 (GND), J2.A12 (GND), J2.B1 (GND), J2.B12 (GND), J2.S1 (SHIELD), J3.2, J4.1, J5.1, OL1.4 (GND), R2.2, R4.2, R5.2, R6.1, R7.1, R8.1, R10.2, SW1.C, SW2.2, SW4.2, U2.2 (GND), U3.5 (GND), U3.21 (GND), U3.24 (GND), U4.2 (GND), U5.2 (VSS)
LED_INDICATOR: D17.2 (A), U3.2 (P1.10)
LED_UNDERGLOW: D4.4 (DIN), U3.36 (P1.00)
unnamed: A1.2 (ROW), D26.2 (A)
unnamed: B1.2 (ROW), D51.2 (A)
unnamed: B2.2 (ROW), D27.2 (A)
unnamed: Backslash1.2 (ROW), D80.2 (A)
unnamed: Bspc1.2 (ROW), Bspc2.2 (ROW), D79.2 (A)
unnamed: C1.2 (ROW), D42.2 (A)
unnamed: C18.1, D16.1 (K), Q2.2 (S), U2.1 (VIN), U2.3 (EN)
unnamed: Cap1.2 (ROW), Cap_Step1.2 (ROW), D21.2 (A)
unnamed: Colon1.2 (ROW), D68.2 (A)
unnamed: Comma1.2 (ROW), D64.2 (A)
unnamed: D1.2 (ROW), D36.2 (A)
unnamed: D2.2 (DOUT), D3.4 (DIN)
unnamed: D4.2 (DOUT), D5.4 (DIN)
unnamed: D5.2 (DOUT), D7.4 (DIN)
unnamed: D6.2 (DOUT), D8.4 (DIN)
unnamed: D7.2 (DOUT), D9.4 (DIN)
unnamed: D10.2 (DOUT), D12.4 (DIN)
unnamed: D8.2 (DOUT), D10.4 (DIN)
unnamed: D11.2 (DOUT), D13.4 (DIN)
unnamed: D9.2 (DOUT), D11.4 (DIN)
unnamed: D12.2 (DOUT), D14.4 (DIN)
unnamed: D13.2 (DOUT), D15.4 (DIN)
unnamed: D2.4 (DIN), D14.2 (DOUT)
unnamed: D6.4 (DIN), D15.2 (DOUT)
unnamed: D17.1 (K), R8.2
unnamed: D18.1 (K), R9.1
unnamed: D19.2 (A), Esc1.2 (ROW)
unnamed: D20.2 (A), Tab1.2 (ROW)
unnamed: D22.2 (A), L_Shift1.2 (ROW)
unnamed: D23.2 (A), L_Ctrl1.2 (ROW)
unnamed: D24.2 (A), Num_1.2 (ROW)
unnamed: D25.2 (A), Q1.2 (ROW)
unnamed: D28.2 (A), L_GUI1.2 (ROW)
unnamed: D29.2 (A), Num_2.2 (ROW)
unnamed: D30.2 (A), W1.2 (ROW)
unnamed: D31.2 (A), S1.2 (ROW)
unnamed: D32.2 (A), Z1.2 (ROW)
unnamed: D33.2 (A), L_Alt1.2 (ROW)
unnamed: D34.2 (A), Num_3.2 (ROW)
unnamed: D35.2 (A), E1.2 (ROW)
unnamed: D37.2 (A), X1.2 (ROW)
unnamed: D38.2 (A), Space_2.75.2 (ROW)
unnamed: D39.2 (A), Num_4.2 (ROW)
unnamed: D40.2 (A), R1.2 (ROW)
unnamed: D41.2 (A), F1.2 (ROW)
unnamed: D43.2 (A), Num_5.2 (ROW)
unnamed: D44.2 (A), T1.2 (ROW)
unnamed: D45.2 (A), G1.2 (ROW)
unnamed: D46.2 (A), V1.2 (ROW)
unnamed: D48.2 (A), Num_6.2 (ROW)
unnamed: D49.2 (A), Y1.2 (ROW)
unnamed: D50.2 (A), H1.2 (ROW)
unnamed: D52.2 (A), Num_7.2 (ROW)
unnamed: D53.2 (A), U1.2 (ROW)
unnamed: D54.2 (A), J1.2 (ROW)
unnamed: D55.2 (A), N1.2 (ROW)
unnamed: D56.2 (A), Space_2.25.2 (ROW)
unnamed: D57.2 (A), Num_8.2 (ROW)
unnamed: D58.2 (A), I1.2 (ROW)
unnamed: D59.2 (A), K1.2 (ROW)
unnamed: D60.2 (A), M1.2 (ROW)
unnamed: D61.2 (A), Num_9.2 (ROW)
unnamed: D62.2 (A), O1.2 (ROW)
unnamed: D63.2 (A), L1.2 (ROW)
unnamed: D65.2 (A), R_Alt1.2 (ROW)
unnamed: D66.2 (A), Num_0.2 (ROW)
unnamed: D67.2 (A), P1.2 (ROW)
unnamed: D69.2 (A), Dot1.2 (ROW)
unnamed: D70.2 (A), Fn1.2 (ROW)
unnamed: D71.2 (A), Minus1.2 (ROW)
unnamed: D72.2 (A), L_Brc1.2 (ROW)
unnamed: D73.2 (A), Quote1.2 (ROW)
unnamed: D74.2 (A), Slash1.2 (ROW)
unnamed: D75.2 (A), R_Ctrl1.2 (ROW)
unnamed: D76.2 (A), Equal1.2 (ROW)
unnamed: D77.2 (A), R_Brc1.2 (ROW)
unnamed: D78.2 (A), left1.2 (ROW)
unnamed: D81.2 (A), R_Shift1.2 (ROW)
unnamed: D82.2 (A), Down1.2 (ROW)
unnamed: D84.2 (A), Del1.2 (ROW)
unnamed: D85.2 (A), Enter1.2 (ROW)
unnamed: D86.2 (A), Up1.2 (ROW)
unnamed: D87.2 (A), Right1.2 (ROW)
unnamed: F2.2, J2.A4 (VBUS), J2.A9 (VBUS), J2.B4 (VBUS), J2.B9 (VBUS), U4.5 (VBUS)
unnamed: J2.A5 (CC1), R6.2
unnamed: J2.A6 (D+), J2.B6 (D+), U4.1 (IO1)
unnamed: J2.A7 (D-), J2.B7 (D-), U4.3 (IO2)
unnamed: J2.B5 (CC2), R7.2
unnamed: Q2.3 (D), R3.1, SW3.3 (C)
unnamed: R9.2, U5.1 (STAT)
unnamed: R10.1, U5.5 (PROG)
POWER_PIN: Q3.1 (G), R5.1, U3.17 (P1.09)
PROG: D25.1 (K), D35.1 (K), D44.1 (K), D53.1 (K), D62.1 (K), D72.1 (K), D80.1 (K), U3.15 (P0.05/AIN3)
RESET: SW2.1, SW4.1, U3.26 (P0.18/RESET)
ROW0: D24.1 (K), D34.1 (K), D43.1 (K), D52.1 (K), D61.1 (K), D71.1 (K), D79.1 (K), U3.35 (P0.24)
ROW1: D19.1 (K), D29.1 (K), D39.1 (K), D48.1 (K), D57.1 (K), D66.1 (K), D76.1 (K), D84.1 (K), U3.33 (P0.13)
ROW3: D20.1 (K), D30.1 (K), D40.1 (K), D49.1 (K), D58.1 (K), D67.1 (K), D77.1 (K), D83.1 (K), U3.32 (P0.20)
ROW4: D26.1 (K), D36.1 (K), D45.1 (K), D54.1 (K), D63.1 (K), D73.1 (K), U3.34 (P0.22)
ROW5: D21.1 (K), D31.1 (K), D41.1 (K), D50.1 (K), D59.1 (K), D68.1 (K), D85.1 (K), U3.22 (P0.07)
ROW6: D22.1 (K), D27.1 (K), D37.1 (K), D46.1 (K), D60.1 (K), D69.1 (K), D81.1 (K), U3.9 (P0.31/AIN7)
ROW7: D32.1 (K), D42.1 (K), D51.1 (K), D55.1 (K), D64.1 (K), D74.1 (K), D86.1 (K), U3.8 (P0.29/AIN5)
ROW8: D28.1 (K), D38.1 (K), D65.1 (K), D75.1 (K), D82.1 (K), U3.3 (P0.03/AIN1)
ROW9: D23.1 (K), D33.1 (K), D56.1 (K), D70.1 (K), D78.1 (K), D87.1 (K), U3.1 (P1.11)
RS1: D83.2 (A), SW1.S1
Rot_A: C15.1, JP2.1 (A), R11.1, R13.2, SW1.A
Rot_B: C16.1, JP1.1 (A), R12.1, R14.2, SW1.B
Rotary_A: JP2.2 (B), R13.1, U3.41 (P0.09/NFC1)
Rotary_B: JP1.2 (B), R14.1, U3.43 (P0.10/NFC2)
SCL: OL1.2 (SCL), U3.30 (P0.17)
SDA: OL1.1 (SDA), U3.28 (P0.15)
SWC: J3.4, U3.39 (SWDCLK)
SWD: J3.3, U3.37 (SWDIO)
VBAT: C20.1, J4.2, SW3.2 (B), U5.3 (VBAT)
VBUS: D16.2 (A), D18.2 (A), F2.1, J5.4, Q2.1 (G), R2.1, U3.27 (VBUS), U5.4 (VDD)
nRF_VDD: C19.1, J3.1, Q3.2 (S), U2.5 (VOUT), U3.19 (VDD), U3.23 (VDDH)

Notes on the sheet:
RProg = 1000/IBat IBat in amps
RProg 10k 5k 2.5k 2k 1.25k
IBat 100mA 200mA 400mA 500mA 800mA
Mounting hole for PCB to plate
Battery connector. the battery will still charging if disconnected.
Programmer connector
USB external connector
Reset Switch one under spacebar (for easy access) one in bottom
Unused PIN
USB type C connection
In case not using filtering/cap, just jumper the connection

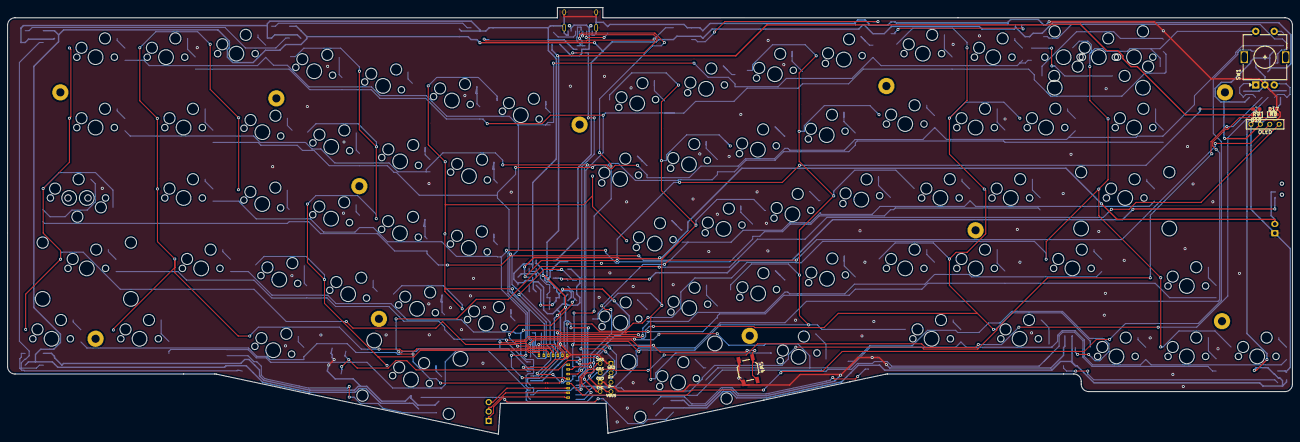
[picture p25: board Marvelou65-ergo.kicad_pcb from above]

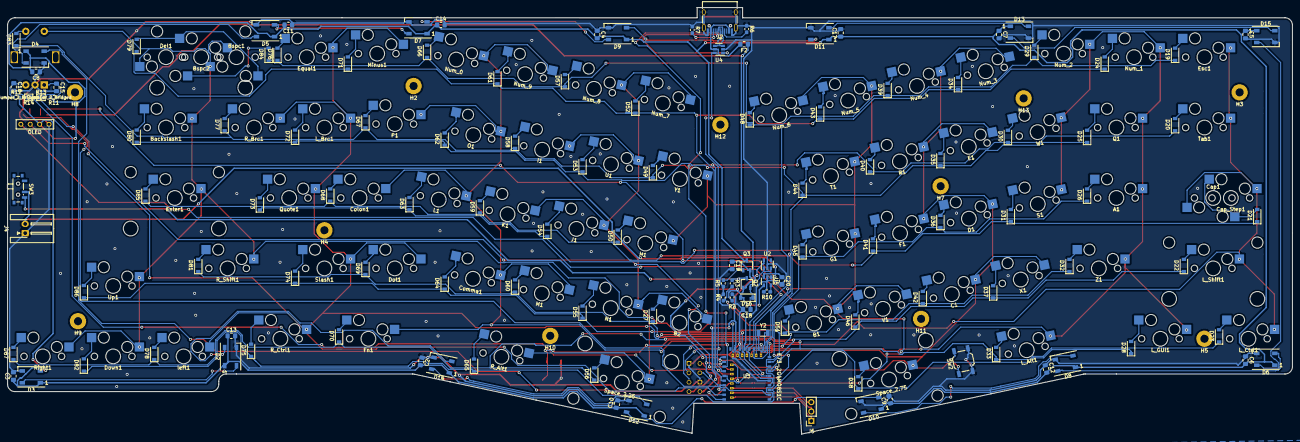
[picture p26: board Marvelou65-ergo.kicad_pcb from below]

Board: 2 copper layers, 347.7 x 115.4 mm, 217 parts (141 on the bottom side), 135 nets.

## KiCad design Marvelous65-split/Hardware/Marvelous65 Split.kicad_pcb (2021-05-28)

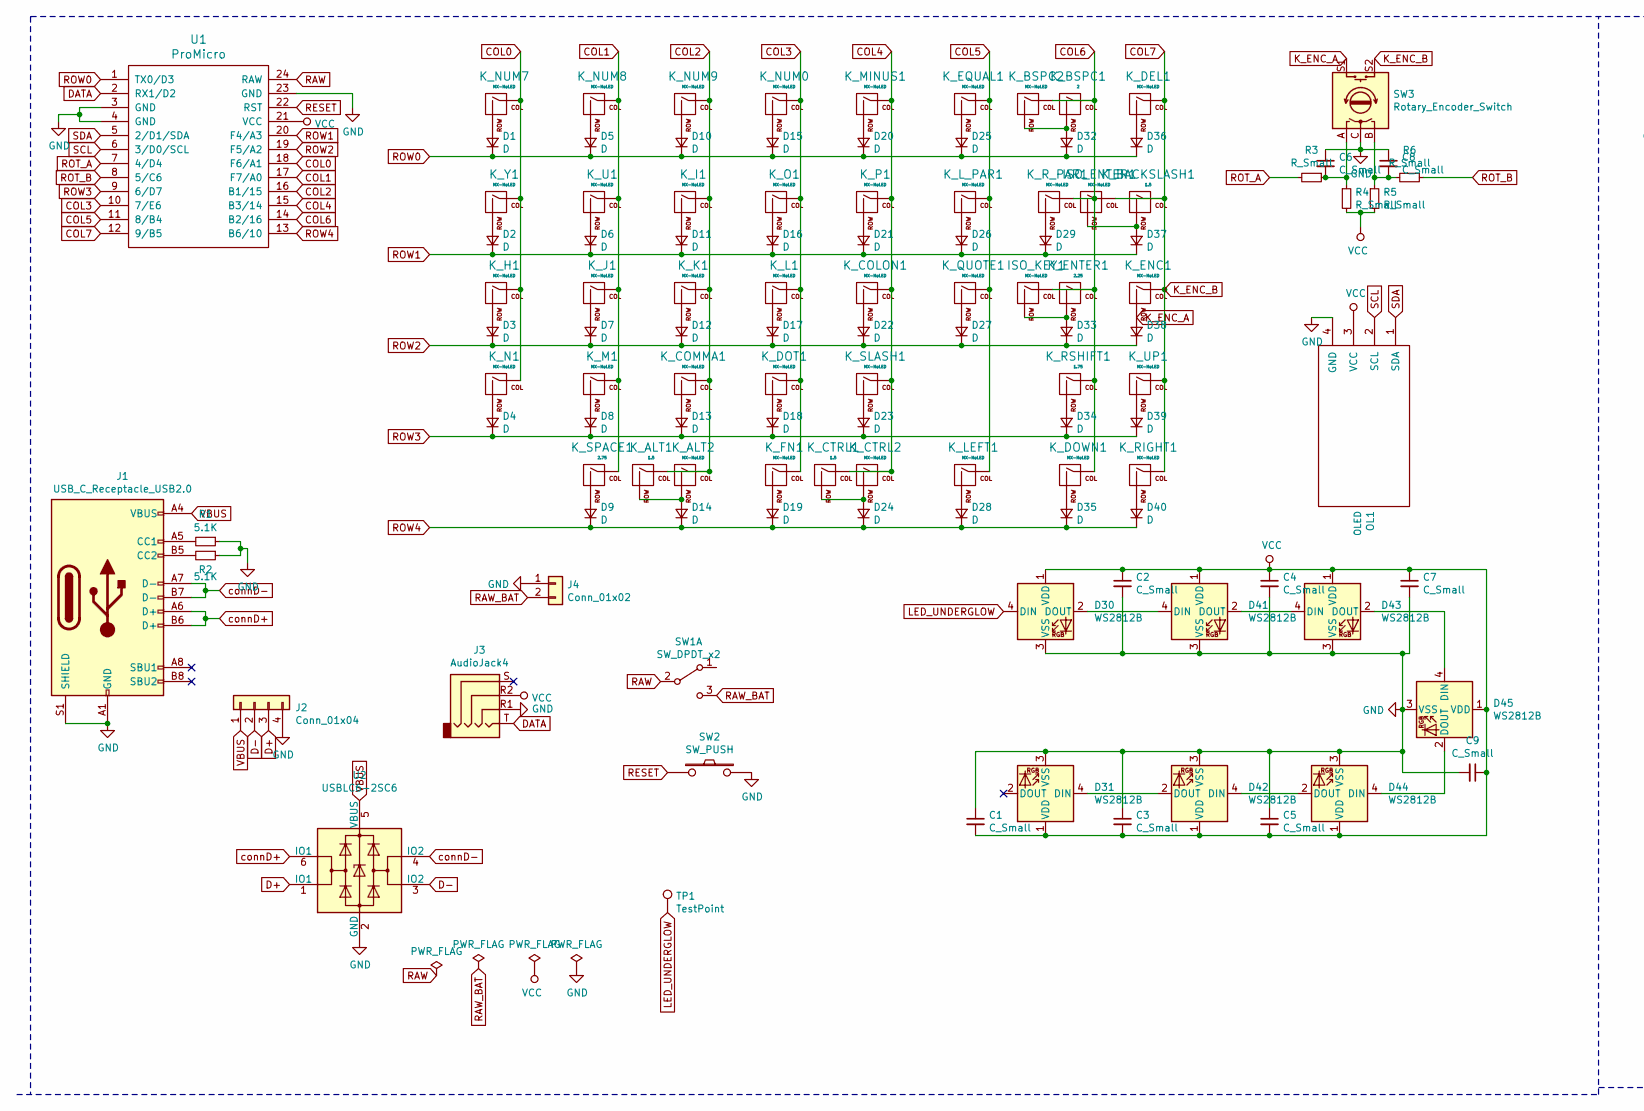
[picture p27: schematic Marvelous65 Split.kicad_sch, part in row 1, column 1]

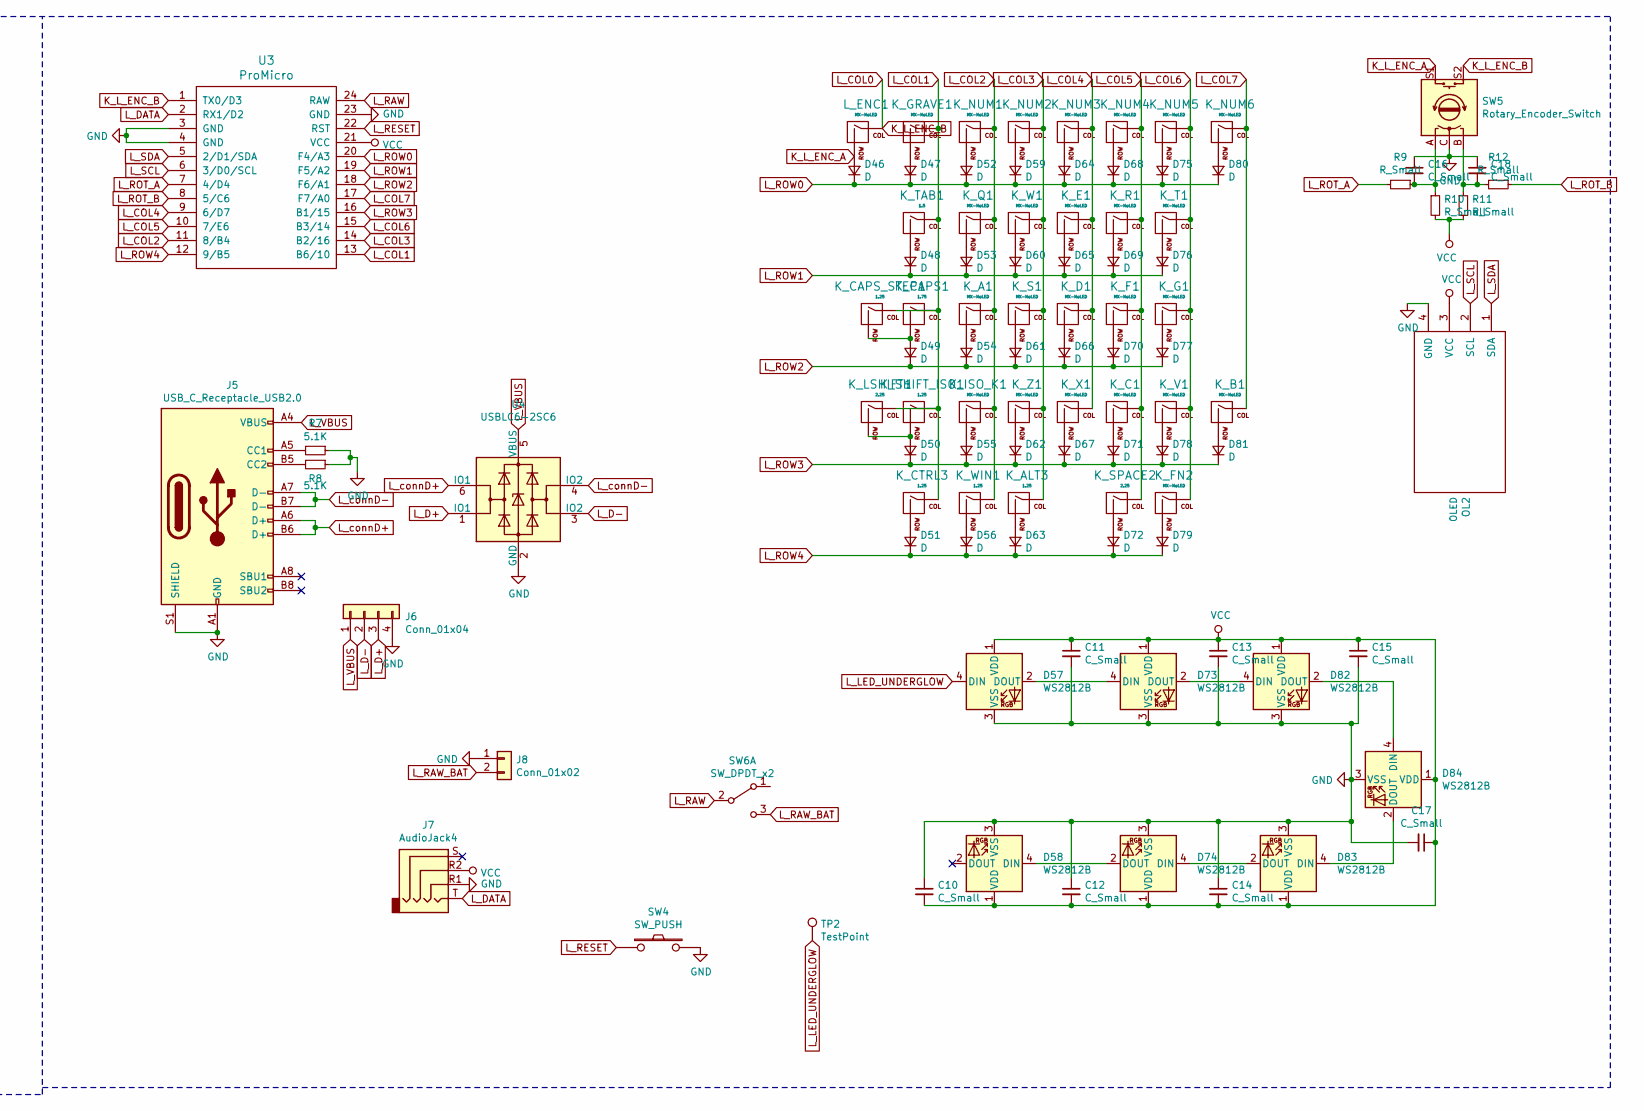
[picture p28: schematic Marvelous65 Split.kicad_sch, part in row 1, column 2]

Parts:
C1, C2, C3, C4, C5, C6, C7, C8, C9, C10, C11, C12, C13, C14, C15, C16, C17, C18: C_Small; C_0805_2012Metric_Pad1.15x1.40mm_HandSolder
D1, D2, D3, D4, D5, D6, D7, D8, D9, D10, D11, D12, D13, D14, D15, D16, D17, D18, D19, D20, D21, D22, D23, D24, D25, D26, D27, D28, D29, D32, D33, D34, D35, D36, D37, D38, D39, D40, D46, D47, D48, D49, D50, D51, D52, D53, D54, D55, D56, D59, D60, D61, D62, D63, D64, D65, D66, D67, D68, D69, D70, D71, D72, D75, D76, D77, D78, D79, D80, D81: D; D_SOD-123
D30, D31, D41, D42, D43, D44, D45, D57, D58, D73, D74, D82, D83, D84: WS2812B; LED_WS2812B_PLCC4_5.0x5.0mm_P3.2mm
ISO_ENTER1: MX-NoLED; MXOnly-ISO-ROTATED-ReversedStabilizers-NoLED
ISO_KEY1: MX-NoLED; MXOnly-1U-NoLED
J1, J5: USB_C_Receptacle_USB2.0; USB_C_Receptacle_HRO_TYPE-C-31-M-12
J2, J6: Conn_01x04; PinSocket_1x04_P2.54mm_Vertical
J3, J7: AudioJack4; Jack_3.5mm_PJ320D_Horizontal
J4, J8: Conn_01x02; JST_XH_S2B-XH-A_1x02_P2.50mm_Horizontal
K_A1: MX-NoLED; MXOnly-1U-NoLED
K_ALT1: 1.5; MXOnly-1.5U-NoLED
K_ALT2: MX-NoLED; MXOnly-1U-NoLED
K_ALT3: 1.25; MXOnly-1.25U-NoLED
K_B1: MX-NoLED; MXOnly-1U-NoLED
K_BACKSLASH1: 1.5; MXOnly-1.5U-NoLED
K_BSPC1: 2; MXOnly-2U-NoLED
K_BSPC2: MX-NoLED; MXOnly-1U-NoLED
K_C1: MX-NoLED; MXOnly-1U-NoLED
K_CAPS1: 1.75; MXOnly-1.75U-NoLED
K_CAPS_STEP1: 1.25; MXOnly-1.25U-NoLED
K_COLON1: MX-NoLED; MXOnly-1U-NoLED
K_COMMA1: MX-NoLED; MXOnly-1U-NoLED
K_CTRL1: 1.5; MXOnly-1.5U-NoLED
K_CTRL2: MX-NoLED; MXOnly-1U-NoLED
K_CTRL3: 1.25; MXOnly-1.25U-NoLED
K_D1: MX-NoLED; MXOnly-1U-NoLED
K_DEL1: MX-NoLED; MXOnly-1U-NoLED
K_DOT1: MX-NoLED; MXOnly-1U-NoLED
K_DOWN1: MX-NoLED; MXOnly-1U-NoLED
K_E1: MX-NoLED; MXOnly-1U-NoLED
K_ENC1: MX-NoLED; MXOnly-1U-NoLED
K_ENTER1: 2.25; MXOnly-2.25U-NoLED
K_EQUAL1: MX-NoLED; MXOnly-1U-NoLED
K_F1: MX-NoLED; MXOnly-1U-NoLED
K_FN1: MX-NoLED; MXOnly-1U-NoLED
K_FN2: MX-NoLED; MXOnly-1.25U-NoLED
K_G1: MX-NoLED; MXOnly-1U-NoLED
K_GRAVE1: MX-NoLED; MXOnly-1U-NoLED
K_H1: MX-NoLED; MXOnly-1U-NoLED
K_I1: MX-NoLED; MXOnly-1U-NoLED
K_ISO_K1: MX-NoLED; MXOnly-1U-NoLED
K_J1: MX-NoLED; MXOnly-1U-NoLED
K_K1: MX-NoLED; MXOnly-1U-NoLED
K_L1: MX-NoLED; MXOnly-1U-NoLED
K_LEFT1: MX-NoLED; MXOnly-1U-NoLED
K_LSHIFT1: 2.25; MXOnly-2.25U-NoLED
K_L_PAR1: MX-NoLED; MXOnly-1U-NoLED
K_M1: MX-NoLED; MXOnly-1U-NoLED
K_MINUS1: MX-NoLED; MXOnly-1U-NoLED
K_N1: MX-NoLED; MXOnly-1U-NoLED
K_NUM0, K_NUM1, K_NUM2, K_NUM3, K_NUM4, K_NUM5, K_NUM6, K_NUM7, K_NUM8, K_NUM9: MX-NoLED; MXOnly-1U-NoLED
K_O1: MX-NoLED; MXOnly-1U-NoLED
K_P1: MX-NoLED; MXOnly-1U-NoLED
K_Q1: MX-NoLED; MXOnly-1U-NoLED
K_QUOTE1: MX-NoLED; MXOnly-1U-NoLED
K_R1: MX-NoLED; MXOnly-1U-NoLED
K_RIGHT1: MX-NoLED; MXOnly-1U-NoLED
K_RSHIFT1: 1.75; MXOnly-1.75U-NoLED
K_R_PAR1: MX-NoLED; MXOnly-1U-NoLED
K_S1: MX-NoLED; MXOnly-1U-NoLED
K_SHIFT_ISO1: 1.25; MXOnly-1.25U-NoLED
K_SLASH1: MX-NoLED; MXOnly-1U-NoLED
K_SPACE1: 2.75; MXOnly-2.75U-ReversedStabilizers-NoLED
K_SPACE2: 2.25; MXOnly-2.25U-ReversedStabilizers-NoLED
K_T1: MX-NoLED; MXOnly-1U-NoLED
K_TAB1: 1.5; MXOnly-1.5U-NoLED
K_U1: MX-NoLED; MXOnly-1U-NoLED
K_UP1: MX-NoLED; MXOnly-1U-NoLED
K_V1: MX-NoLED; MXOnly-1U-NoLED
K_W1: MX-NoLED; MXOnly-1U-NoLED
K_WIN1: 1.25; MXOnly-1.25U-NoLED
K_X1: MX-NoLED; MXOnly-1U-NoLED
K_Y1: MX-NoLED; MXOnly-1U-NoLED
K_Z1: MX-NoLED; MXOnly-1U-NoLED
L_ENC1: MX-NoLED; MXOnly-1U-NoLED
OL1, OL2: OLED
R1, R2, R7, R8: 5.1K; R_0603_1608Metric_Pad1.05x0.95mm_HandSolder
R3, R4, R5, R6, R9, R10, R11, R12: R_Small; R_0603_1608Metric_Pad1.05x0.95mm_HandSolder
SW1, SW6: SW_DPDT_x2; SW_SPDT_PCM12
SW2, SW4: SW_PUSH; SW_SPST_TL3342
SW3, SW5: Rotary_Encoder_Switch; RotaryEncoder_Alps_EC11E-Switch_Vertical_H20mm
TP1, TP2: TestPoint; TestPoint_THTPad_D2.5mm_Drill1.2mm
U1, U3: ProMicro; ProMicro_v3
U2, U4: USBLC6-2SC6; SOT-23-6

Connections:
COL0: K_H1.1 (COL), K_N1.1 (COL), K_NUM7.1 (COL), K_Y1.1 (COL), U1.18 (F6/A1)
COL1: K_J1.1 (COL), K_M1.1 (COL), K_NUM8.1 (COL), K_SPACE1.1 (COL), K_U1.1 (COL), U1.17 (F7/A0)
COL2: K_ALT1.1 (COL), K_ALT2.1 (COL), K_COMMA1.1 (COL), K_I1.1 (COL), K_K1.1 (COL), K_NUM9.1 (COL), U1.16 (B1/15)
COL3: K_DOT1.1 (COL), K_FN1.1 (COL), K_L1.1 (COL), K_NUM0.1 (COL), K_O1.1 (COL), U1.10 (7/E6)
COL4: K_COLON1.1 (COL), K_CTRL1.1 (COL), K_CTRL2.1 (COL), K_MINUS1.1 (COL), K_P1.1 (COL), K_SLASH1.1 (COL), U1.15 (B3/14)
COL5: K_EQUAL1.1 (COL), K_LEFT1.1 (COL), K_L_PAR1.1 (COL), K_QUOTE1.1 (COL), U1.11 (8/B4)
COL6: ISO_KEY1.1 (COL), K_BSPC1.1 (COL), K_BSPC2.1 (COL), K_DOWN1.1 (COL), K_ENTER1.1 (COL), K_RSHIFT1.1 (COL), K_R_PAR1.1 (COL), U1.14 (B2/16)
COL7: ISO_ENTER1.1 (COL), K_BACKSLASH1.1 (COL), K_DEL1.1 (COL), K_ENC1.1 (COL), K_RIGHT1.1 (COL), K_UP1.1 (COL), SW3.S2, U1.12 (9/B5)
D+: J2.3, U2.1 (IO1)
D-: J2.2, U2.3 (IO2)
DATA: J3.T, U1.2 (RX1/D2)
GND: C1.1, C2.2, C3.1, C4.2, C5.1, C6.1, C7.2, C8.1, C9.2, C10.1, C11.2, C12.1, C13.2, C14.1, C15.2, C16.1, C17.2, C18.1, D30.3 (VSS), D31.3 (VSS), D41.3 (VSS), D42.3 (VSS), D43.3 (VSS), D44.3 (VSS), D45.3 (VSS), D57.3 (VSS), D58.3 (VSS), D73.3 (VSS), D74.3 (VSS), D82.3 (VSS), D83.3 (VSS), D84.3 (VSS), J1.A1 (GND), J1.A12 (GND), J1.B1 (GND), J1.B12 (GND), J1.S1 (SHIELD), J2.4, J3.R1, J4.1, J5.A1 (GND), J5.A12 (GND), J5.B1 (GND), J5.B12 (GND), J5.S1 (SHIELD), J6.4, J7.R1, J8.1, OL1.4 (GND), OL2.4 (GND), R1.1, R2.1, R7.1, R8.1, SW2.2, SW3.C, SW4.2, SW5.C, U1.3 (GND), U1.4 (GND), U1.23 (GND), U2.2 (GND), U3.3 (GND), U3.4 (GND), U3.23 (GND), U4.2 (GND)
K_ENC_A: D38.2 (A), K_ENC1.2 (ROW), SW3.S1
K_L_ENC_A: D46.2 (A), L_ENC1.2 (ROW), SW5.S1
K_L_ENC_B: L_ENC1.1 (COL), SW5.S2, U3.1 (TX0/D3)
LED_UNDERGLOW: D30.4 (DIN), TP1.1
L_COL1: K_CAPS1.1 (COL), K_CAPS_STEP1.1 (COL), K_CTRL3.1 (COL), K_GRAVE1.1 (COL), K_LSHIFT1.1 (COL), K_SHIFT_ISO1.1 (COL), K_TAB1.1 (COL), U3.13 (B6/10)
L_COL2: K_A1.1 (COL), K_ISO_K1.1 (COL), K_NUM1.1 (COL), K_Q1.1 (COL), K_WIN1.1 (COL), U3.11 (8/B4)
L_COL3: K_ALT3.1 (COL), K_NUM2.1 (COL), K_S1.1 (COL), K_W1.1 (COL), K_Z1.1 (COL), U3.14 (B2/16)
L_COL4: K_D1.1 (COL), K_E1.1 (COL), K_NUM3.1 (COL), K_X1.1 (COL), U3.9 (6/D7)
L_COL5: K_C1.1 (COL), K_F1.1 (COL), K_NUM4.1 (COL), K_R1.1 (COL), K_SPACE2.1 (COL), U3.10 (7/E6)
L_COL6: K_FN2.1 (COL), K_G1.1 (COL), K_NUM5.1 (COL), K_T1.1 (COL), K_V1.1 (COL), U3.15 (B3/14)
L_COL7: K_B1.1 (COL), K_NUM6.1 (COL), U3.17 (F7/A0)
L_D+: J6.3, U4.1 (IO1)
L_D-: J6.2, U4.3 (IO2)
L_DATA: J7.T, U3.2 (RX1/D2)
L_LED_UNDERGLOW: D57.4 (DIN), TP2.1
L_RAW: SW6.2 (B), U3.24 (RAW)
L_RAW_BAT: J8.2, SW6.3 (C)
L_RESET: SW4.1, U3.22 (RST)
L_ROTA_A: C16.2, R9.1, R10.1, SW5.A; also elsewhere on the board
L_ROTA_B: C18.2, R11.1, R12.2, SW5.B; also elsewhere on the board
L_ROT_A: R9.2, U3.7 (4/D4); also elsewhere on the board
L_ROT_B: R12.1, U3.8 (5/C6); also elsewhere on the board
L_ROW0: D46.1 (K), D47.1 (K), D52.1 (K), D59.1 (K), D64.1 (K), D68.1 (K), D75.1 (K), D80.1 (K), U3.20 (F4/A3)
L_ROW1: D48.1 (K), D53.1 (K), D60.1 (K), D65.1 (K), D69.1 (K), D76.1 (K), U3.19 (F5/A2)
L_ROW2: D49.1 (K), D54.1 (K), D61.1 (K), D66.1 (K), D70.1 (K), D77.1 (K), U3.18 (F6/A1)
L_ROW3: D50.1 (K), D55.1 (K), D62.1 (K), D67.1 (K), D71.1 (K), D78.1 (K), D81.1 (K), U3.16 (B1/15)
L_ROW4: D51.1 (K), D56.1 (K), D63.1 (K), D72.1 (K), D79.1 (K), U3.12 (9/B5)
L_SCL: OL2.2 (SCL), U3.6 (3/D0/SCL)
L_SDA: OL2.1 (SDA), U3.5 (2/D1/SDA)
L_VBUS: J5.A4 (VBUS), J5.A9 (VBUS), J5.B4 (VBUS), J5.B9 (VBUS), J6.1, U4.5 (VBUS)
L_connD+: J5.A6 (D+), J5.B6 (D+), U4.6 (IO1)
L_connD-: J5.A7 (D-), J5.B7 (D-), U4.4 (IO2)
unnamed: D1.2 (A), K_NUM7.2 (ROW)
unnamed: D2.2 (A), K_Y1.2 (ROW)
unnamed: D3.2 (A), K_H1.2 (ROW)
unnamed: D4.2 (A), K_N1.2 (ROW)
unnamed: D5.2 (A), K_NUM8.2 (ROW)
unnamed: D6.2 (A), K_U1.2 (ROW)
unnamed: D7.2 (A), K_J1.2 (ROW)
unnamed: D8.2 (A), K_M1.2 (ROW)
unnamed: D9.2 (A), K_SPACE1.2 (ROW)
unnamed: D10.2 (A), K_NUM9.2 (ROW)
unnamed: D11.2 (A), K_I1.2 (ROW)
unnamed: D12.2 (A), K_K1.2 (ROW)
unnamed: D13.2 (A), K_COMMA1.2 (ROW)
unnamed: D14.2 (A), K_ALT1.2 (ROW), K_ALT2.2 (ROW)
unnamed: D15.2 (A), K_NUM0.2 (ROW)
unnamed: D16.2 (A), K_O1.2 (ROW)
unnamed: D17.2 (A), K_L1.2 (ROW)
unnamed: D18.2 (A), K_DOT1.2 (ROW)
unnamed: D19.2 (A), K_FN1.2 (ROW)
unnamed: D20.2 (A), K_MINUS1.2 (ROW)
unnamed: D21.2 (A), K_P1.2 (ROW)
unnamed: D22.2 (A), K_COLON1.2 (ROW)
unnamed: D23.2 (A), K_SLASH1.2 (ROW)
unnamed: D24.2 (A), K_CTRL1.2 (ROW), K_CTRL2.2 (ROW)
unnamed: D25.2 (A), K_EQUAL1.2 (ROW)
unnamed: D26.2 (A), K_L_PAR1.2 (ROW)
unnamed: D27.2 (A), K_QUOTE1.2 (ROW)
unnamed: D28.2 (A), K_LEFT1.2 (ROW)
unnamed: D29.2 (A), K_R_PAR1.2 (ROW)
unnamed: D30.2 (DOUT), D41.4 (DIN)
unnamed: D31.4 (DIN), D42.2 (DOUT)
unnamed: D32.2 (A), K_BSPC1.2 (ROW), K_BSPC2.2 (ROW)
unnamed: D33.2 (A), ISO_KEY1.2 (ROW), K_ENTER1.2 (ROW)
unnamed: D34.2 (A), K_RSHIFT1.2 (ROW)
unnamed: D35.2 (A), K_DOWN1.2 (ROW)
unnamed: D36.2 (A), K_DEL1.2 (ROW)
unnamed: D37.2 (A), ISO_ENTER1.2 (ROW), K_BACKSLASH1.2 (ROW)
unnamed: D39.2 (A), K_UP1.2 (ROW)
unnamed: D40.2 (A), K_RIGHT1.2 (ROW)
unnamed: D41.2 (DOUT), D43.4 (DIN)
unnamed: D42.4 (DIN), D44.2 (DOUT)
unnamed: D43.2 (DOUT), D45.4 (DIN)
unnamed: D44.4 (DIN), D45.2 (DOUT)
unnamed: D47.2 (A), K_GRAVE1.2 (ROW)
unnamed: D48.2 (A), K_TAB1.2 (ROW)
unnamed: D49.2 (A), K_CAPS1.2 (ROW), K_CAPS_STEP1.2 (ROW)
unnamed: D50.2 (A), K_LSHIFT1.2 (ROW), K_SHIFT_ISO1.2 (ROW)
unnamed: D51.2 (A), K_CTRL3.2 (ROW)
unnamed: D52.2 (A), K_NUM1.2 (ROW)
unnamed: D53.2 (A), K_Q1.2 (ROW)
unnamed: D54.2 (A), K_A1.2 (ROW)
unnamed: D55.2 (A), K_ISO_K1.2 (ROW)
unnamed: D56.2 (A), K_WIN1.2 (ROW)
unnamed: D57.2 (DOUT), D73.4 (DIN)
unnamed: D58.4 (DIN), D74.2 (DOUT)
unnamed: D59.2 (A), K_NUM2.2 (ROW)
unnamed: D60.2 (A), K_W1.2 (ROW)
unnamed: D61.2 (A), K_S1.2 (ROW)
unnamed: D62.2 (A), K_Z1.2 (ROW)
unnamed: D63.2 (A), K_ALT3.2 (ROW)
unnamed: D64.2 (A), K_NUM3.2 (ROW)
unnamed: D65.2 (A), K_E1.2 (ROW)
unnamed: D66.2 (A), K_D1.2 (ROW)
unnamed: D67.2 (A), K_X1.2 (ROW)
unnamed: D68.2 (A), K_NUM4.2 (ROW)
unnamed: D69.2 (A), K_R1.2 (ROW)
unnamed: D70.2 (A), K_F1.2 (ROW)
unnamed: D71.2 (A), K_C1.2 (ROW)
unnamed: D72.2 (A), K_SPACE2.2 (ROW)
unnamed: D73.2 (DOUT), D82.4 (DIN)
unnamed: D74.4 (DIN), D83.2 (DOUT)
unnamed: D75.2 (A), K_NUM5.2 (ROW)
unnamed: D76.2 (A), K_T1.2 (ROW)
unnamed: D77.2 (A), K_G1.2 (ROW)
unnamed: D78.2 (A), K_V1.2 (ROW)
unnamed: D79.2 (A), K_FN2.2 (ROW)
unnamed: D80.2 (A), K_NUM6.2 (ROW)
unnamed: D81.2 (A), K_B1.2 (ROW)
unnamed: D82.2 (DOUT), D84.4 (DIN)
unnamed: D83.4 (DIN), D84.2 (DOUT)
unnamed: J1.A5 (CC1), R1.2
unnamed: J1.B5 (CC2), R2.2
unnamed: J5.A5 (CC1), R7.2
unnamed: J5.B5 (CC2), R8.2
RAW: SW1.2 (B), U1.24 (RAW)
RAW_BAT: J4.2, SW1.3 (C)
RESET: SW2.1, U1.22 (RST)
ROTA_A: C6.2, R3.1, R4.1, SW3.A; also elsewhere on the board
ROTA_B: C8.2, R5.1, R6.2, SW3.B; also elsewhere on the board
ROT_A: R3.2, U1.7 (4/D4); also elsewhere on the board
ROT_B: R6.1, U1.8 (5/C6); also elsewhere on the board
ROW0: D1.1 (K), D5.1 (K), D10.1 (K), D15.1 (K), D20.1 (K), D25.1 (K), D32.1 (K), D36.1 (K), U1.1 (TX0/D3)
ROW1: D2.1 (K), D6.1 (K), D11.1 (K), D16.1 (K), D21.1 (K), D26.1 (K), D29.1 (K), D37.1 (K), U1.20 (F4/A3)
ROW2: D3.1 (K), D7.1 (K), D12.1 (K), D17.1 (K), D22.1 (K), D27.1 (K), D33.1 (K), D38.1 (K), U1.19 (F5/A2)
ROW3: D4.1 (K), D8.1 (K), D13.1 (K), D18.1 (K), D23.1 (K), D34.1 (K), D39.1 (K), U1.9 (6/D7)
ROW4: D9.1 (K), D14.1 (K), D19.1 (K), D24.1 (K), D28.1 (K), D35.1 (K), D40.1 (K), U1.13 (B6/10)
SCL: OL1.2 (SCL), U1.6 (3/D0/SCL)
SDA: OL1.1 (SDA), U1.5 (2/D1/SDA)
VBUS: J1.A4 (VBUS), J1.A9 (VBUS), J1.B4 (VBUS), J1.B9 (VBUS), J2.1, U2.5 (VBUS)
VCC: C1.2, C2.1, C3.2, C4.1, C5.2, C7.1, C9.1, C10.2, C11.1, C12.2, C13.1, C14.2, C15.1, C17.1, D30.1 (VDD), D31.1 (VDD), D41.1 (VDD), D42.1 (VDD), D43.1 (VDD), D44.1 (VDD), D45.1 (VDD), D57.1 (VDD), D58.1 (VDD), D73.1 (VDD), D74.1 (VDD), D82.1 (VDD), D83.1 (VDD), D84.1 (VDD), J3.R2, J7.R2, OL1.3 (VCC), OL2.3 (VCC), R4.2, R5.2, R10.2, R11.2, U1.21 (VCC), U3.21 (VCC)
connD+: J1.A6 (D+), J1.B6 (D+), U2.6 (IO1)
connD-: J1.A7 (D-), J1.B7 (D-), U2.4 (IO2)

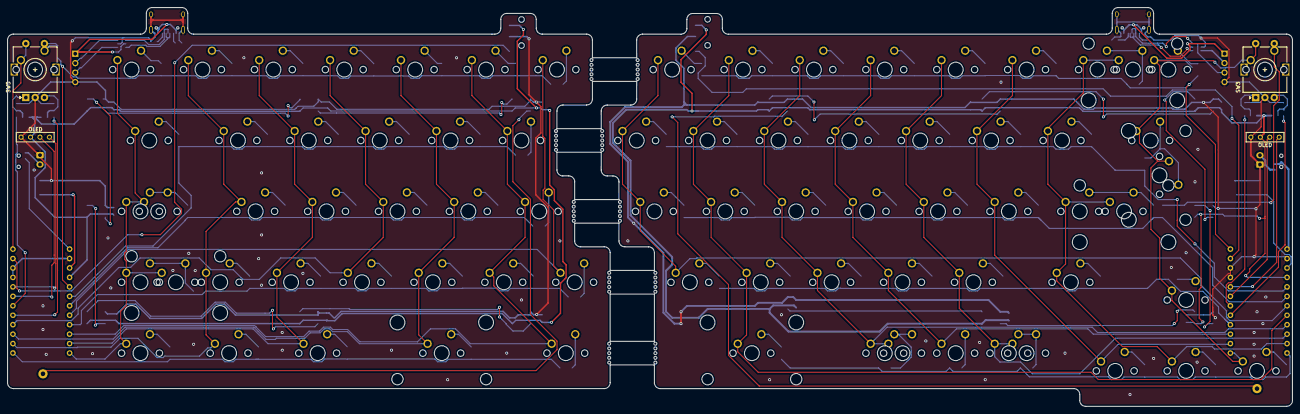
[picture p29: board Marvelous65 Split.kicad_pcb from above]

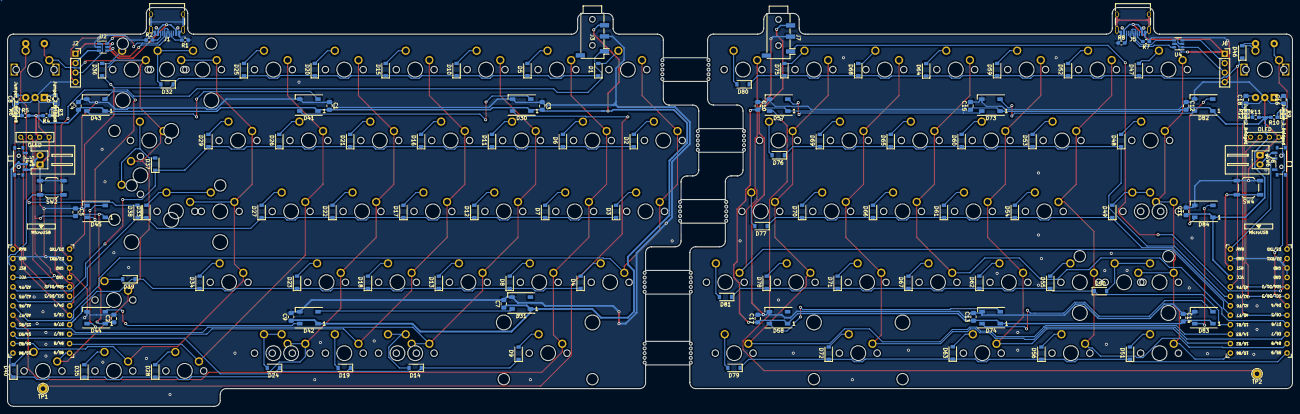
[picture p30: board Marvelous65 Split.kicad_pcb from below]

Board: 2 copper layers, 345.3 x 107.2 mm, 217 parts (137 on the bottom side), 146 nets.

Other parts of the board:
JP1, JP2, JP3, JP4: Jumper_2_Bridged; Jumper

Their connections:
L_ROTA_A: JP3.2; also elsewhere on the board
L_ROTA_B: JP4.2; also elsewhere on the board
L_ROT_A: JP3.1; also elsewhere on the board
L_ROT_B: JP4.1; also elsewhere on the board
ROTA_A: JP2.1; also elsewhere on the board
ROTA_B: JP1.1; also elsewhere on the board
ROT_A: JP2.2; also elsewhere on the board
ROT_B: JP1.2; also elsewhere on the board

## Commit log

2021-01-22 add case design
2021-01-22 add plate
    [marvelous65 plate.dxf]
2021-01-22 add dust cover design
    [Marvelous65 Dust cover.step]
2021-05-05 add PCB and other files
    [Left middle case.stl, Left top case.stl, Marvelou65 Ergo.sch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]
2021-05-07 Add BOM file for JLC
    add BOM file for fabrication
    [Marvelou65 Revise v2-bom.csv, Marvelou65 Revise v2.sch, Marvelou65-ergo-bom.csv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]
2021-05-28 add IBOM
    [Marvelou65 Revise v2.kicad_pcb, Marvelous65 Split.kicad_pcb]
2021-05-28 fix folder name typo
    [Marvelou65-ergo-bom.csv, Marvelou65-ergo.kicad_pcb, Marvelou65-ergo.sch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]
2021-05-28 add battery image
